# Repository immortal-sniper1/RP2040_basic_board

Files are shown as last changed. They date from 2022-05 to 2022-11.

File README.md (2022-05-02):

# RP2040_board1
 RP2040 test board, breadboard friedly.  
 Features:   
 -Li ion power optin (protection built in) auto switching power in case of usb unpluging   
 -RTC with separate 20mm cell  
 -microSD card slot  
 -all pins exposed (that are not used internaly for a dedicated task)  
 -both LDO and buck switching convertor for power, one of them may be used based on the SPDT switch   
 (later maybe just one of them may be populated and the switch replaced by a solder bridge)   
 -same pinout as rpi pico just wider form factor   
 -all pins labeled   
 -It requires a few extra wires to work since this is a 2 layer design and this was a scarifice 
made in order to keep a solid ground plane under the entire PCB   
 
 Images:  https://imgur.com/a/X6zGeTy

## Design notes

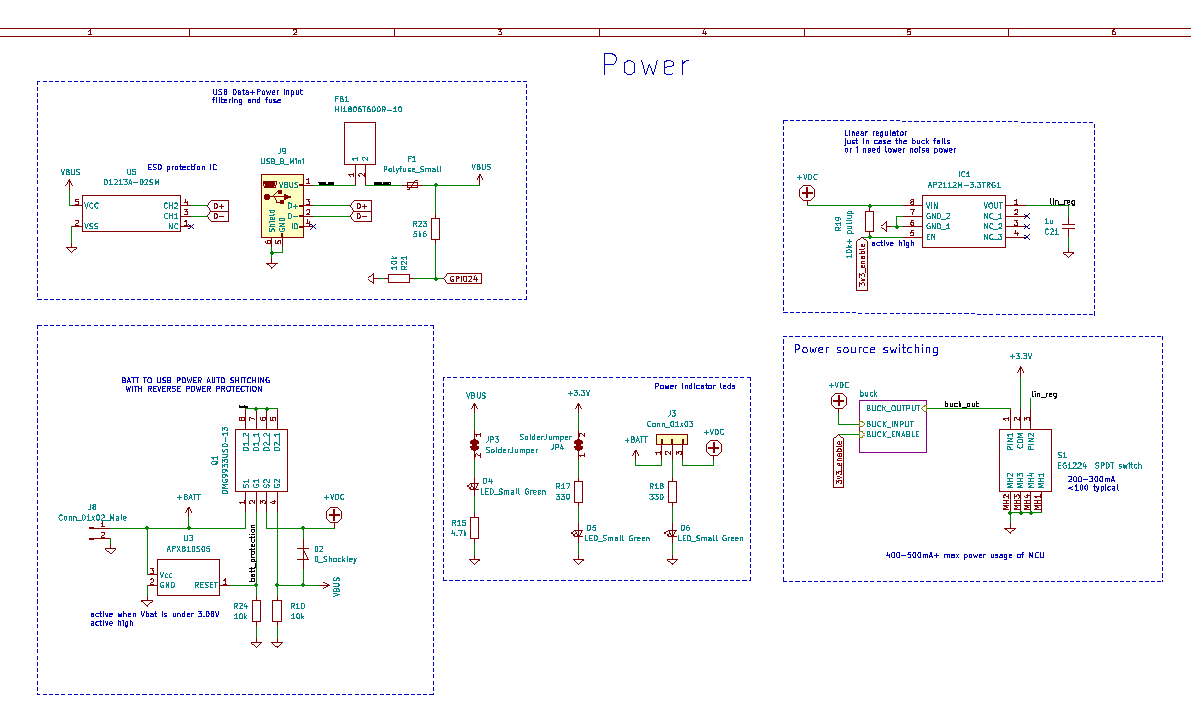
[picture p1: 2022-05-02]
HW_V2/pictures/Untitled3.png

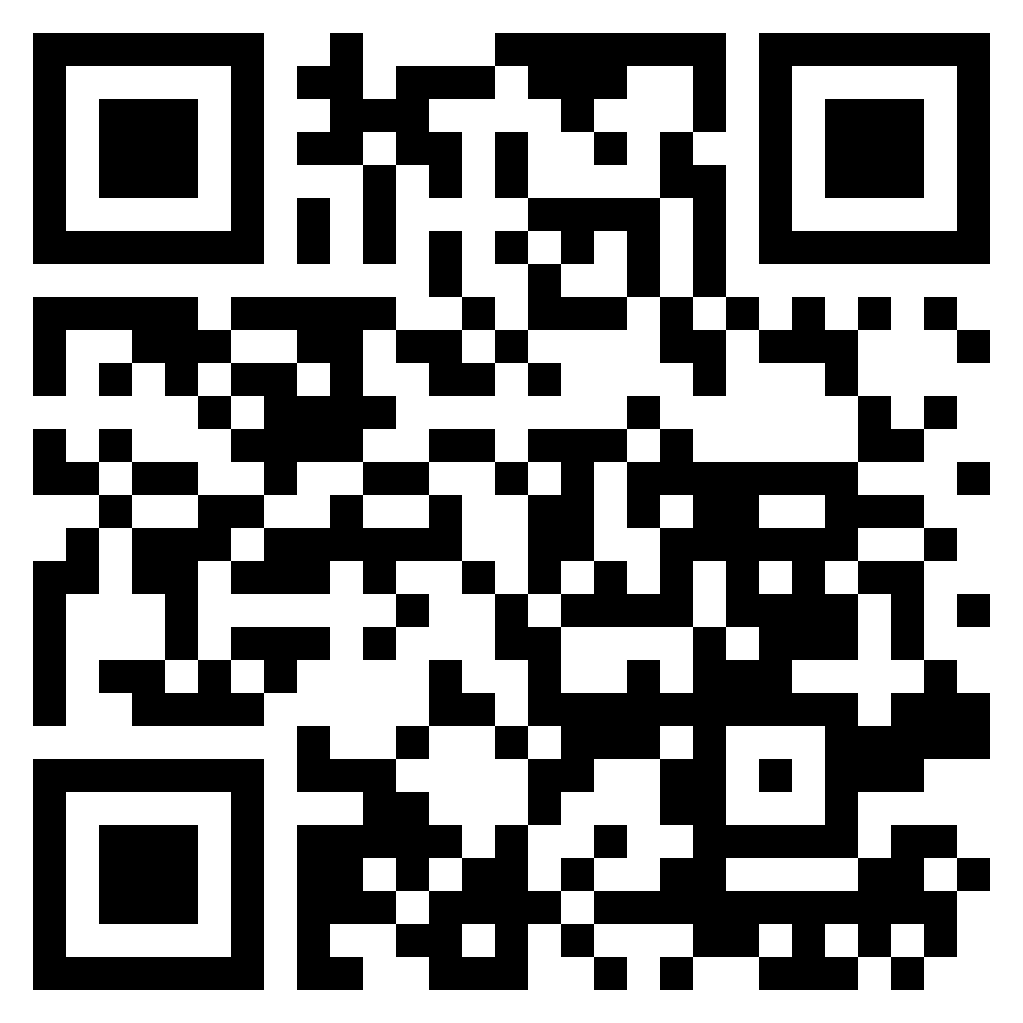
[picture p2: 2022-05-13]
HW_V2/pictures/QR.png

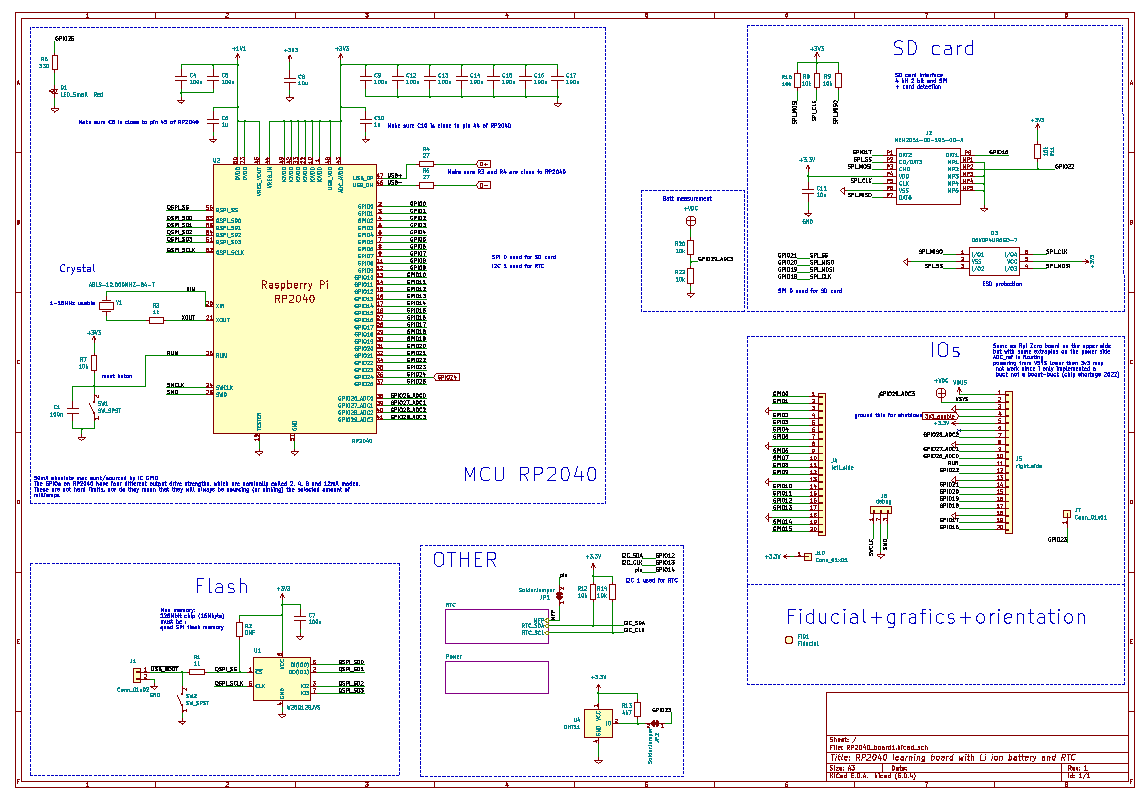
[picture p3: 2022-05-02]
HW_V2/pictures/Untitled1.png

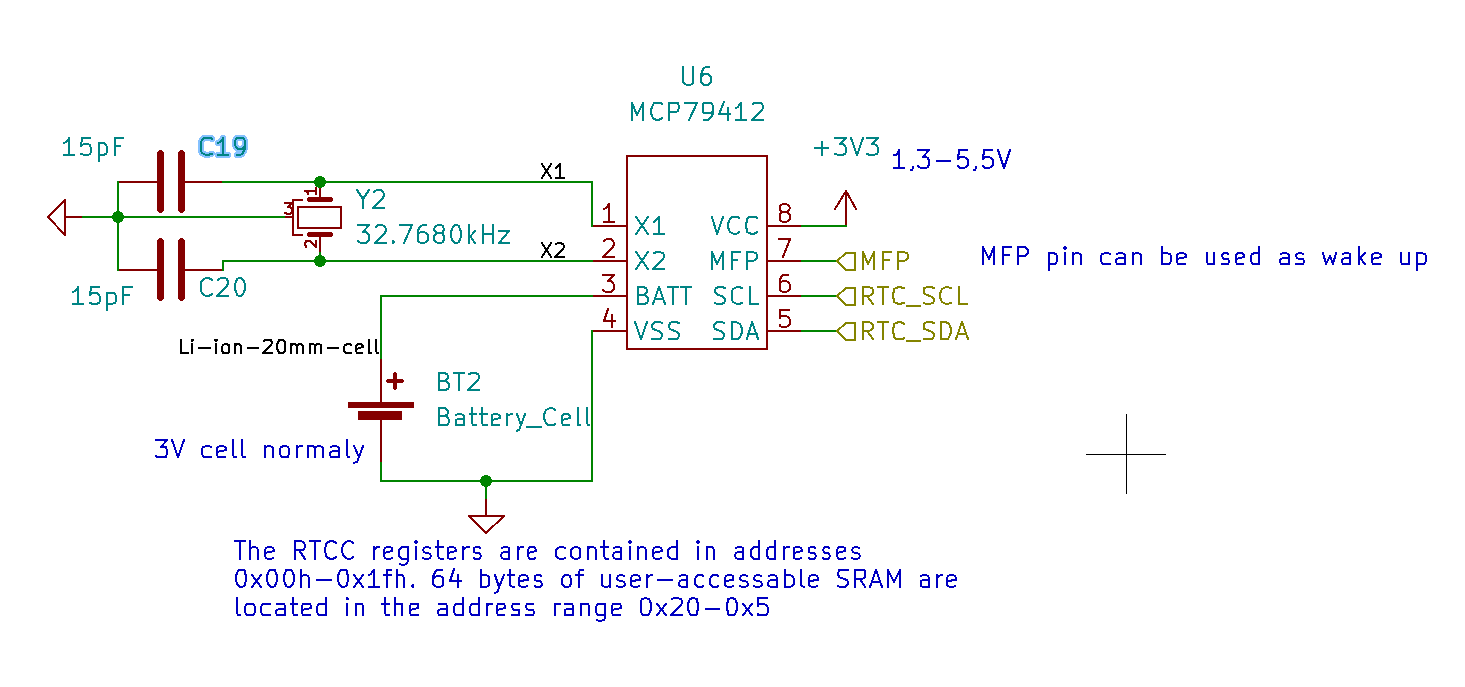
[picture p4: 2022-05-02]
HW_V2/pictures/Untitled2.png

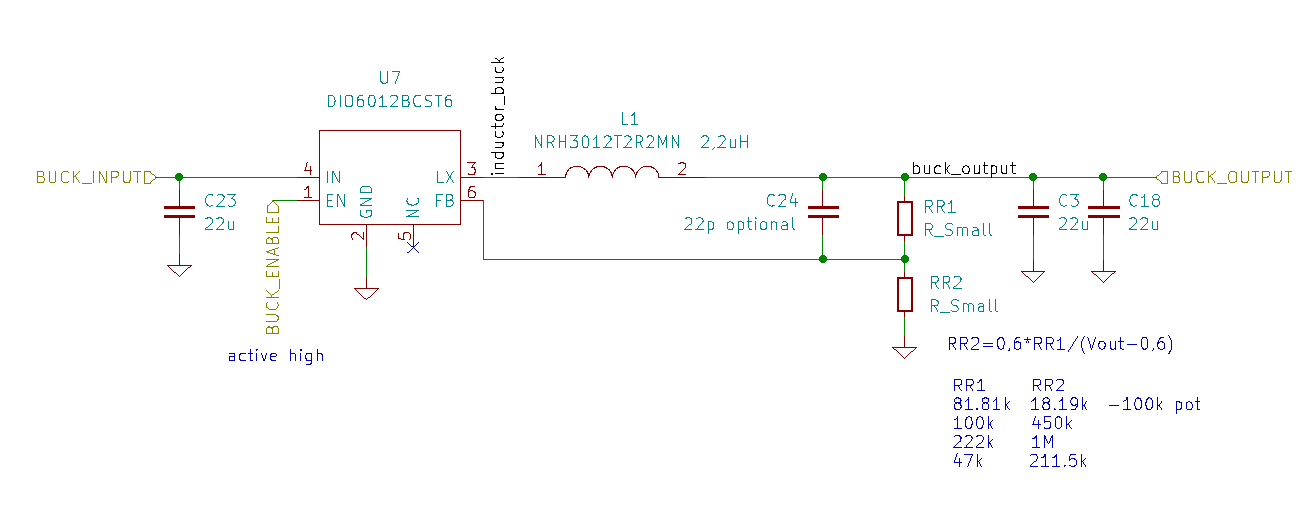
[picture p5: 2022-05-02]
HW_V2/pictures/Untitled4.png

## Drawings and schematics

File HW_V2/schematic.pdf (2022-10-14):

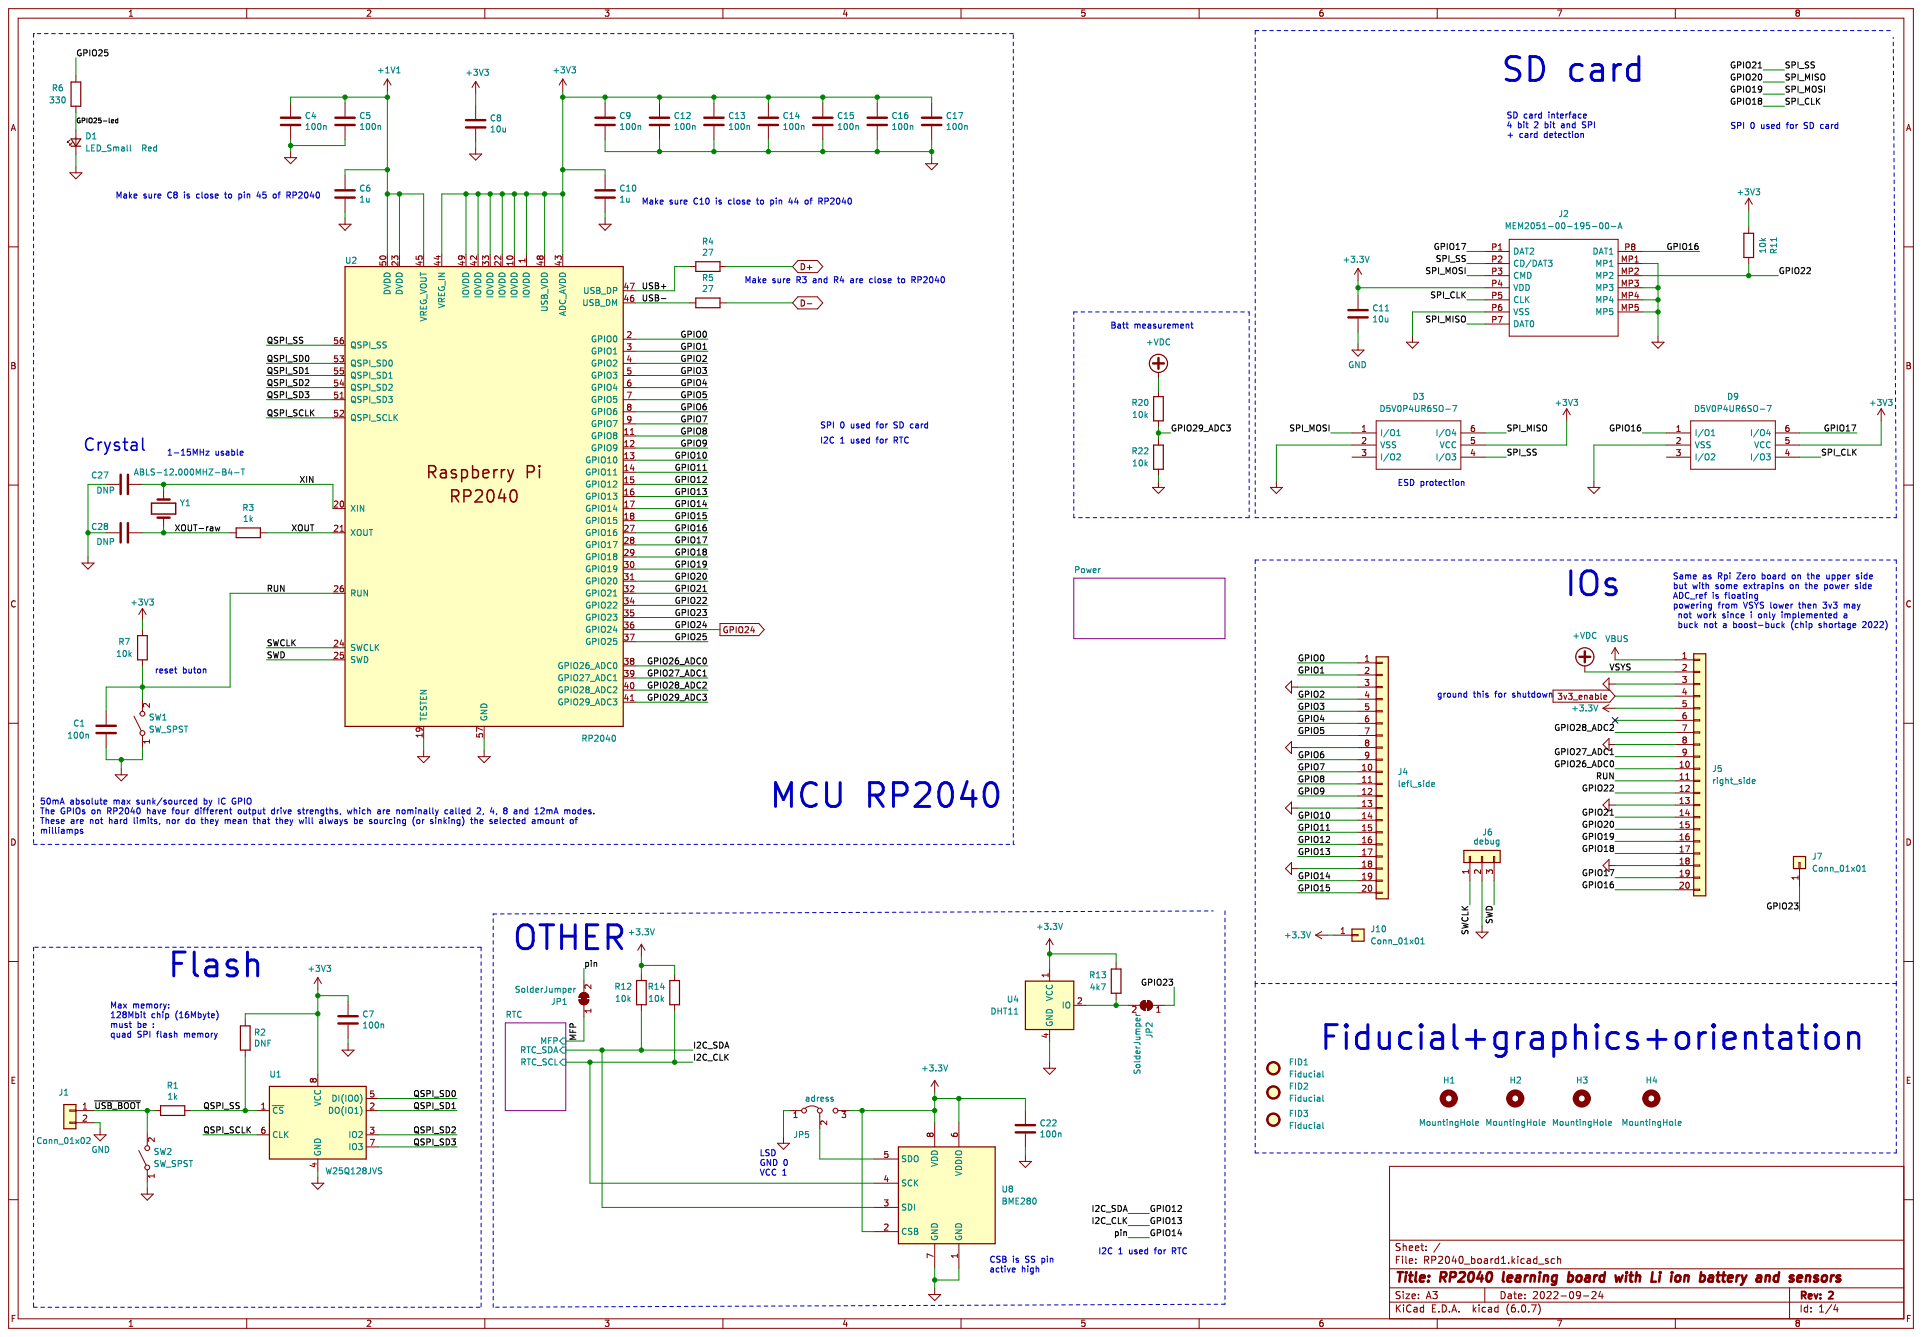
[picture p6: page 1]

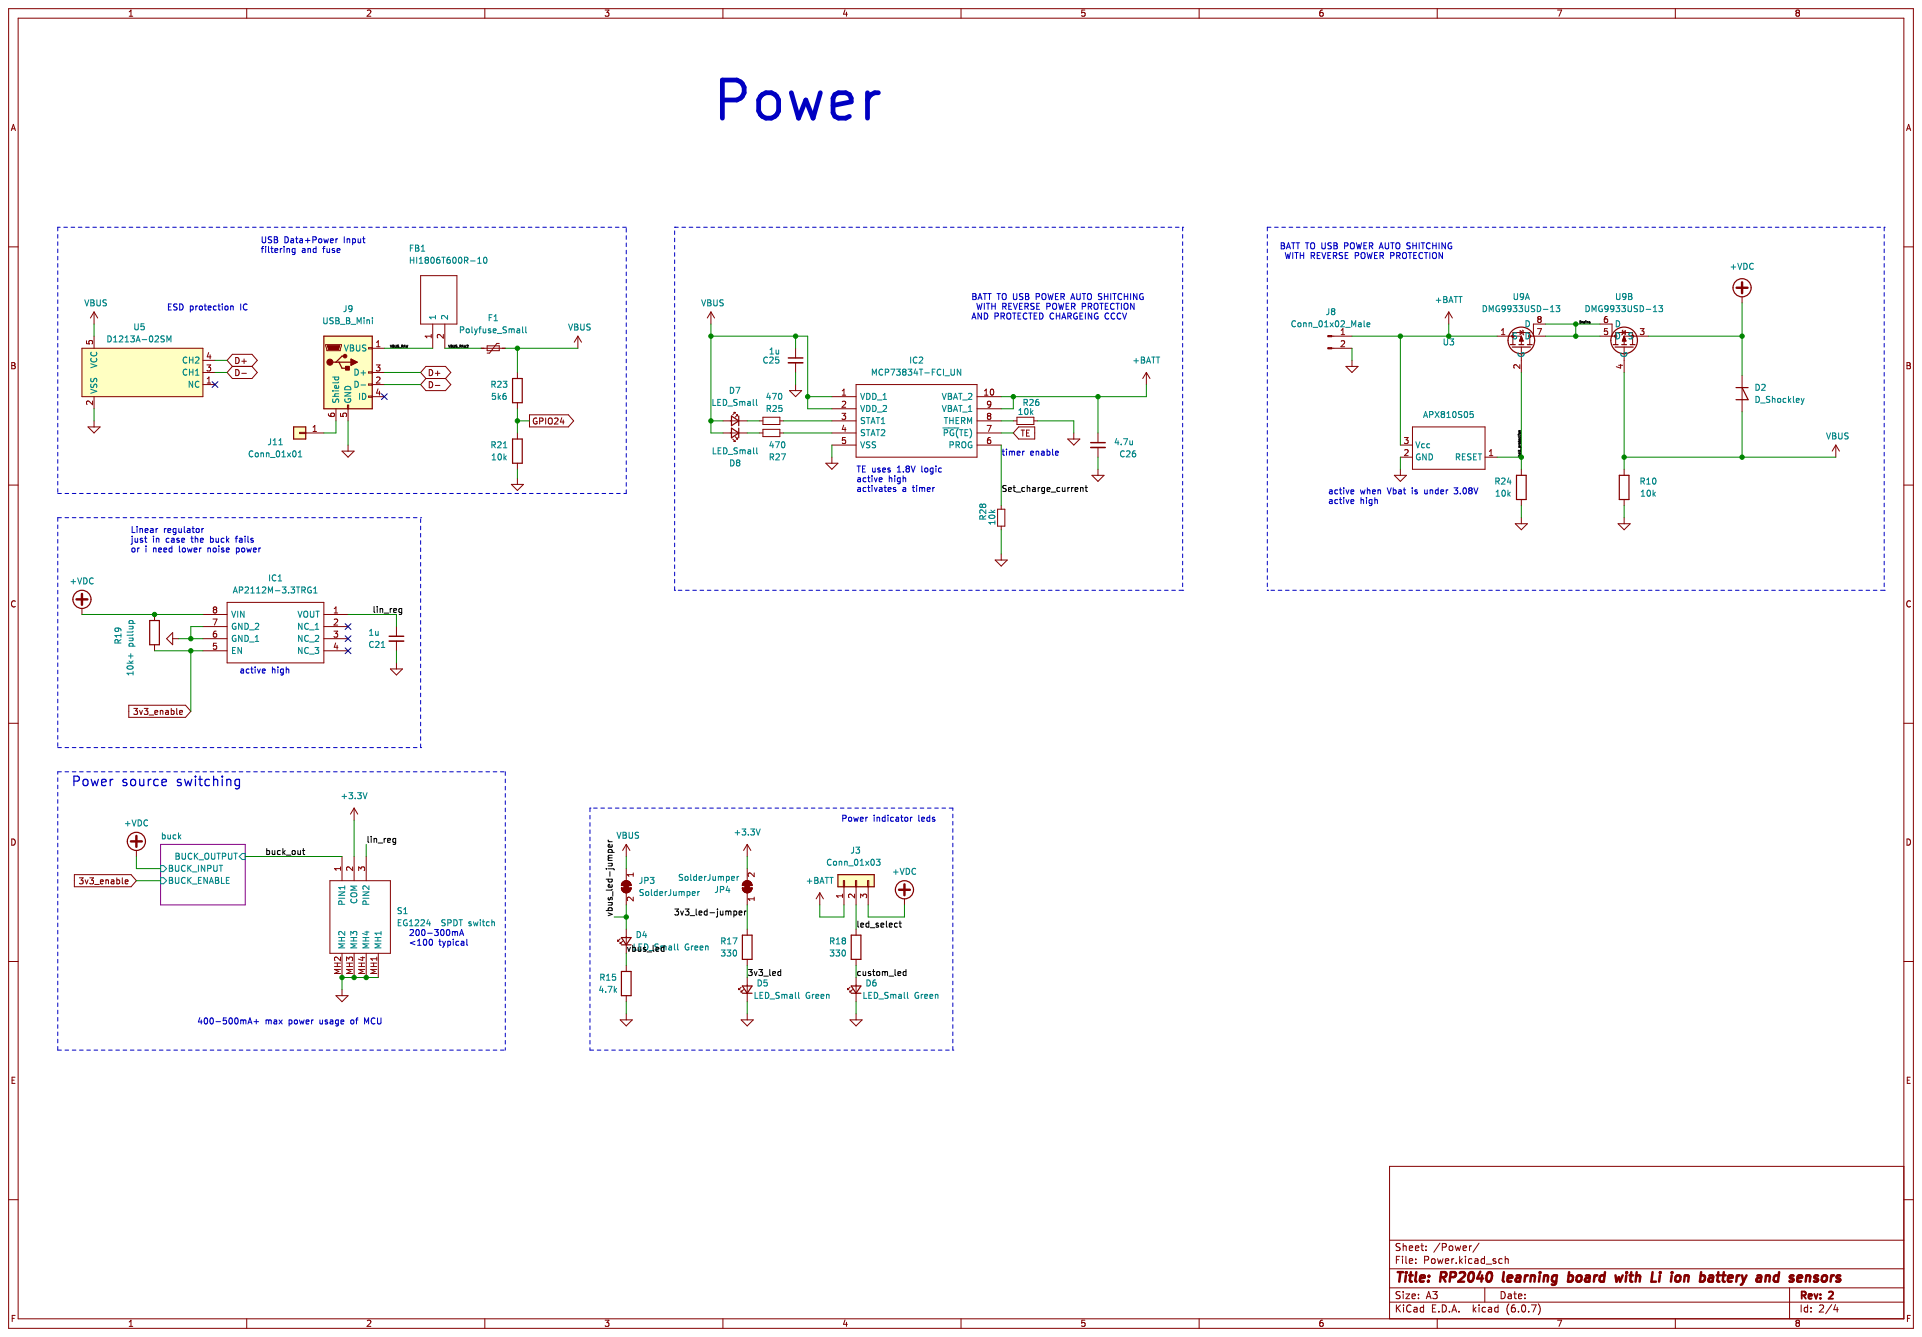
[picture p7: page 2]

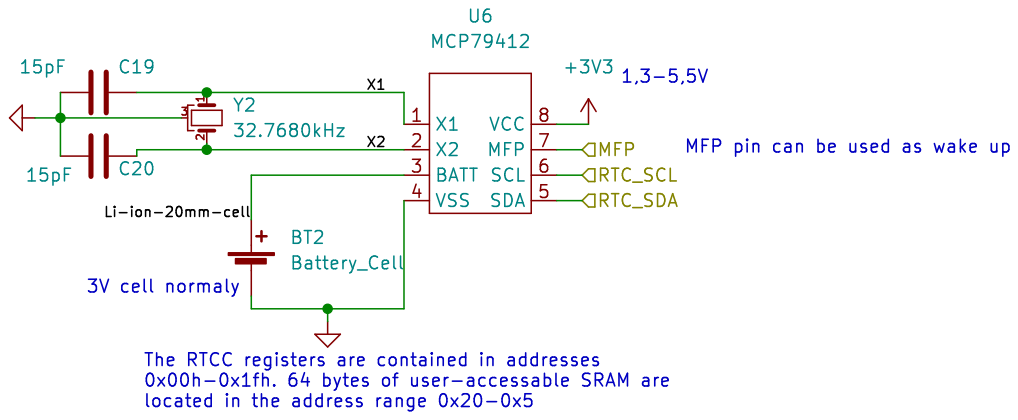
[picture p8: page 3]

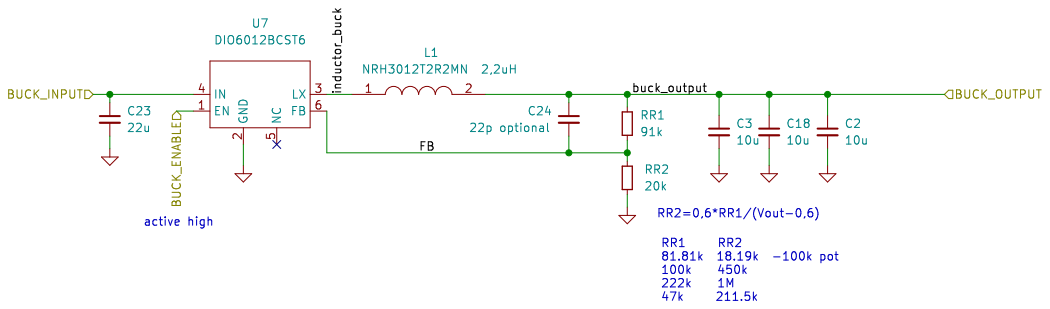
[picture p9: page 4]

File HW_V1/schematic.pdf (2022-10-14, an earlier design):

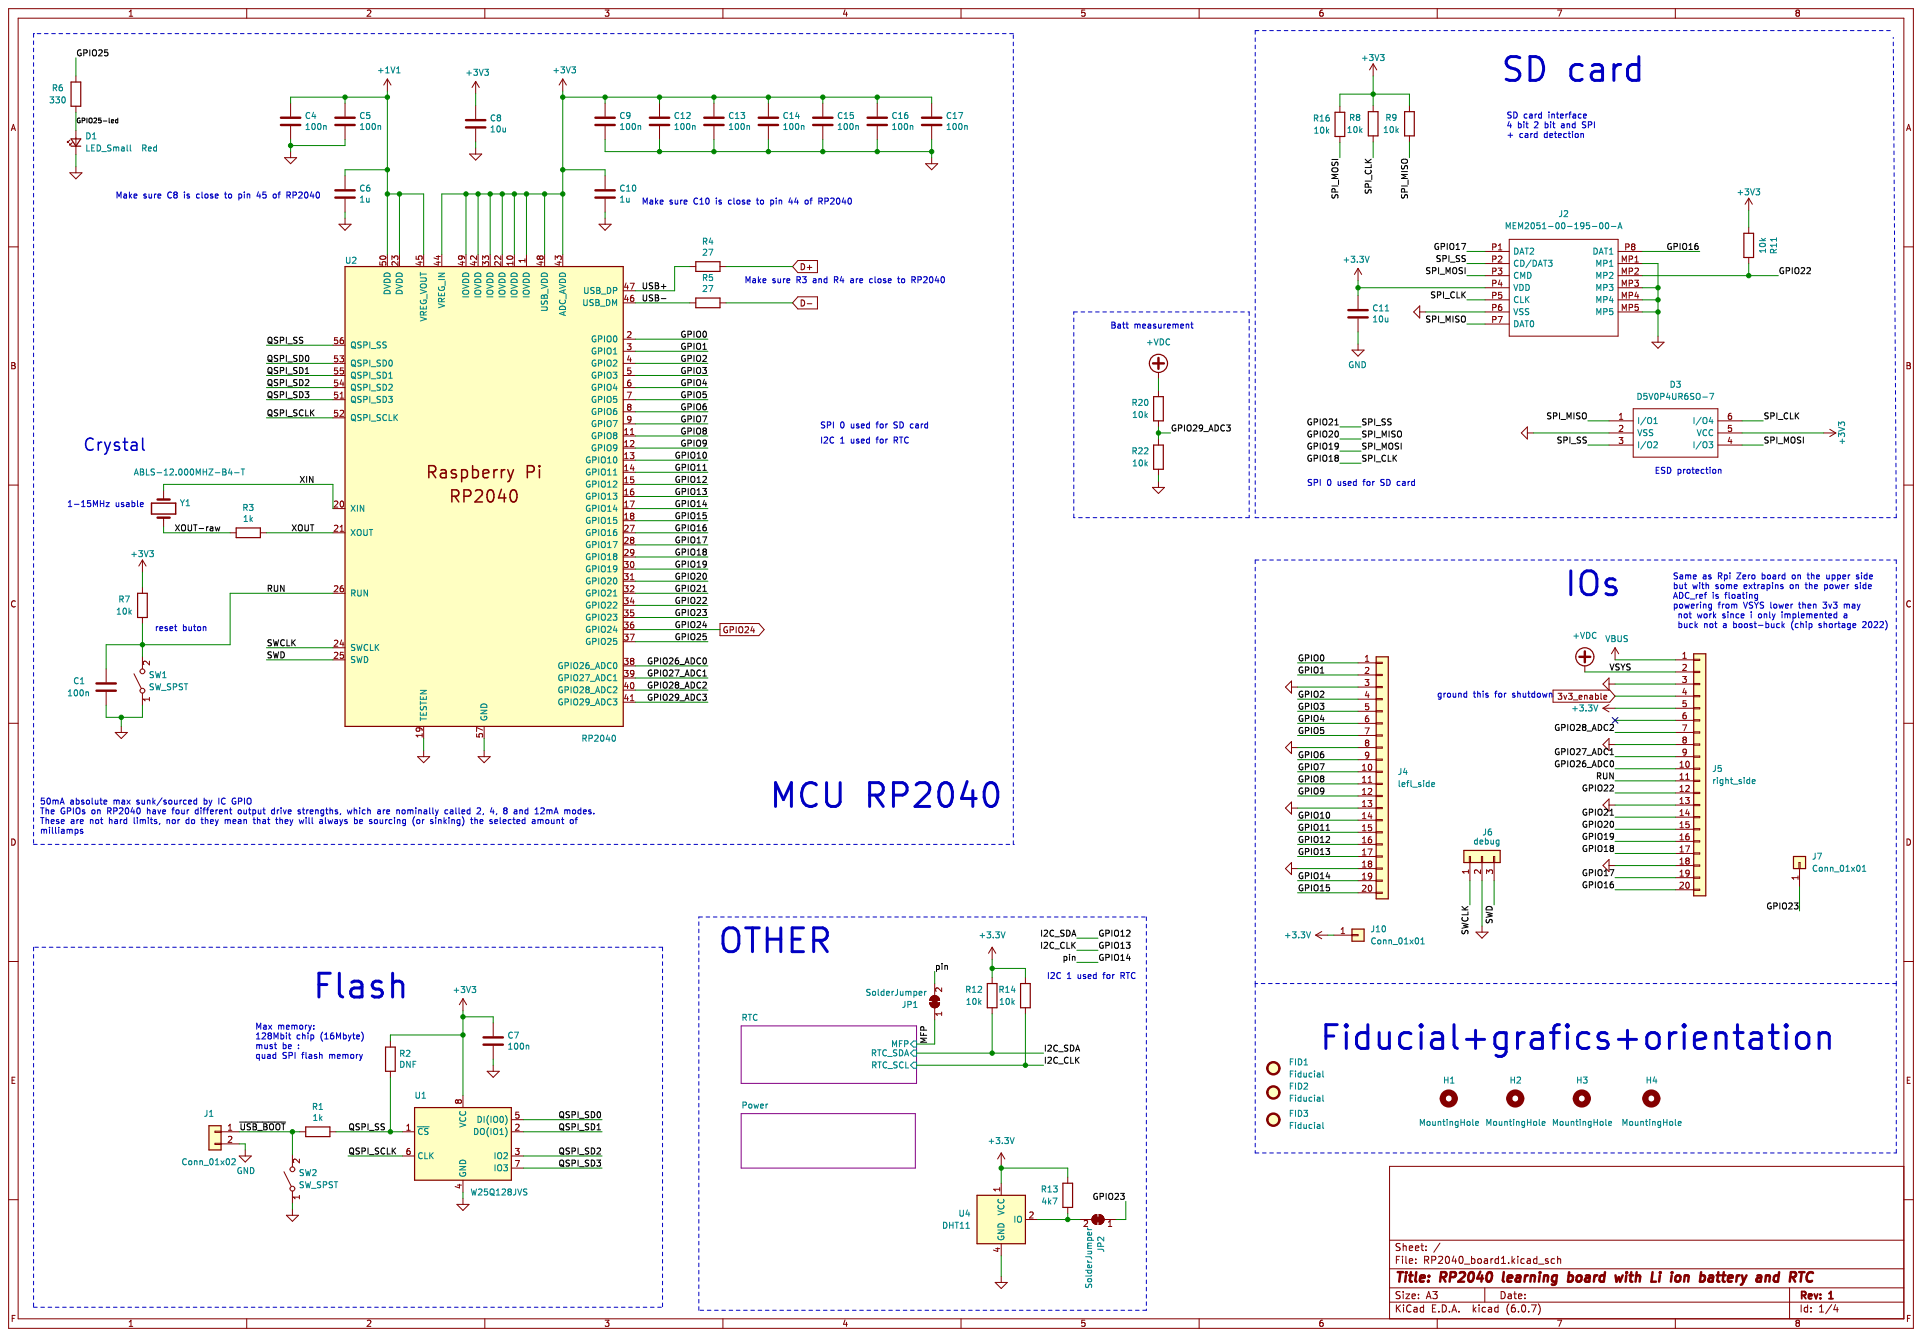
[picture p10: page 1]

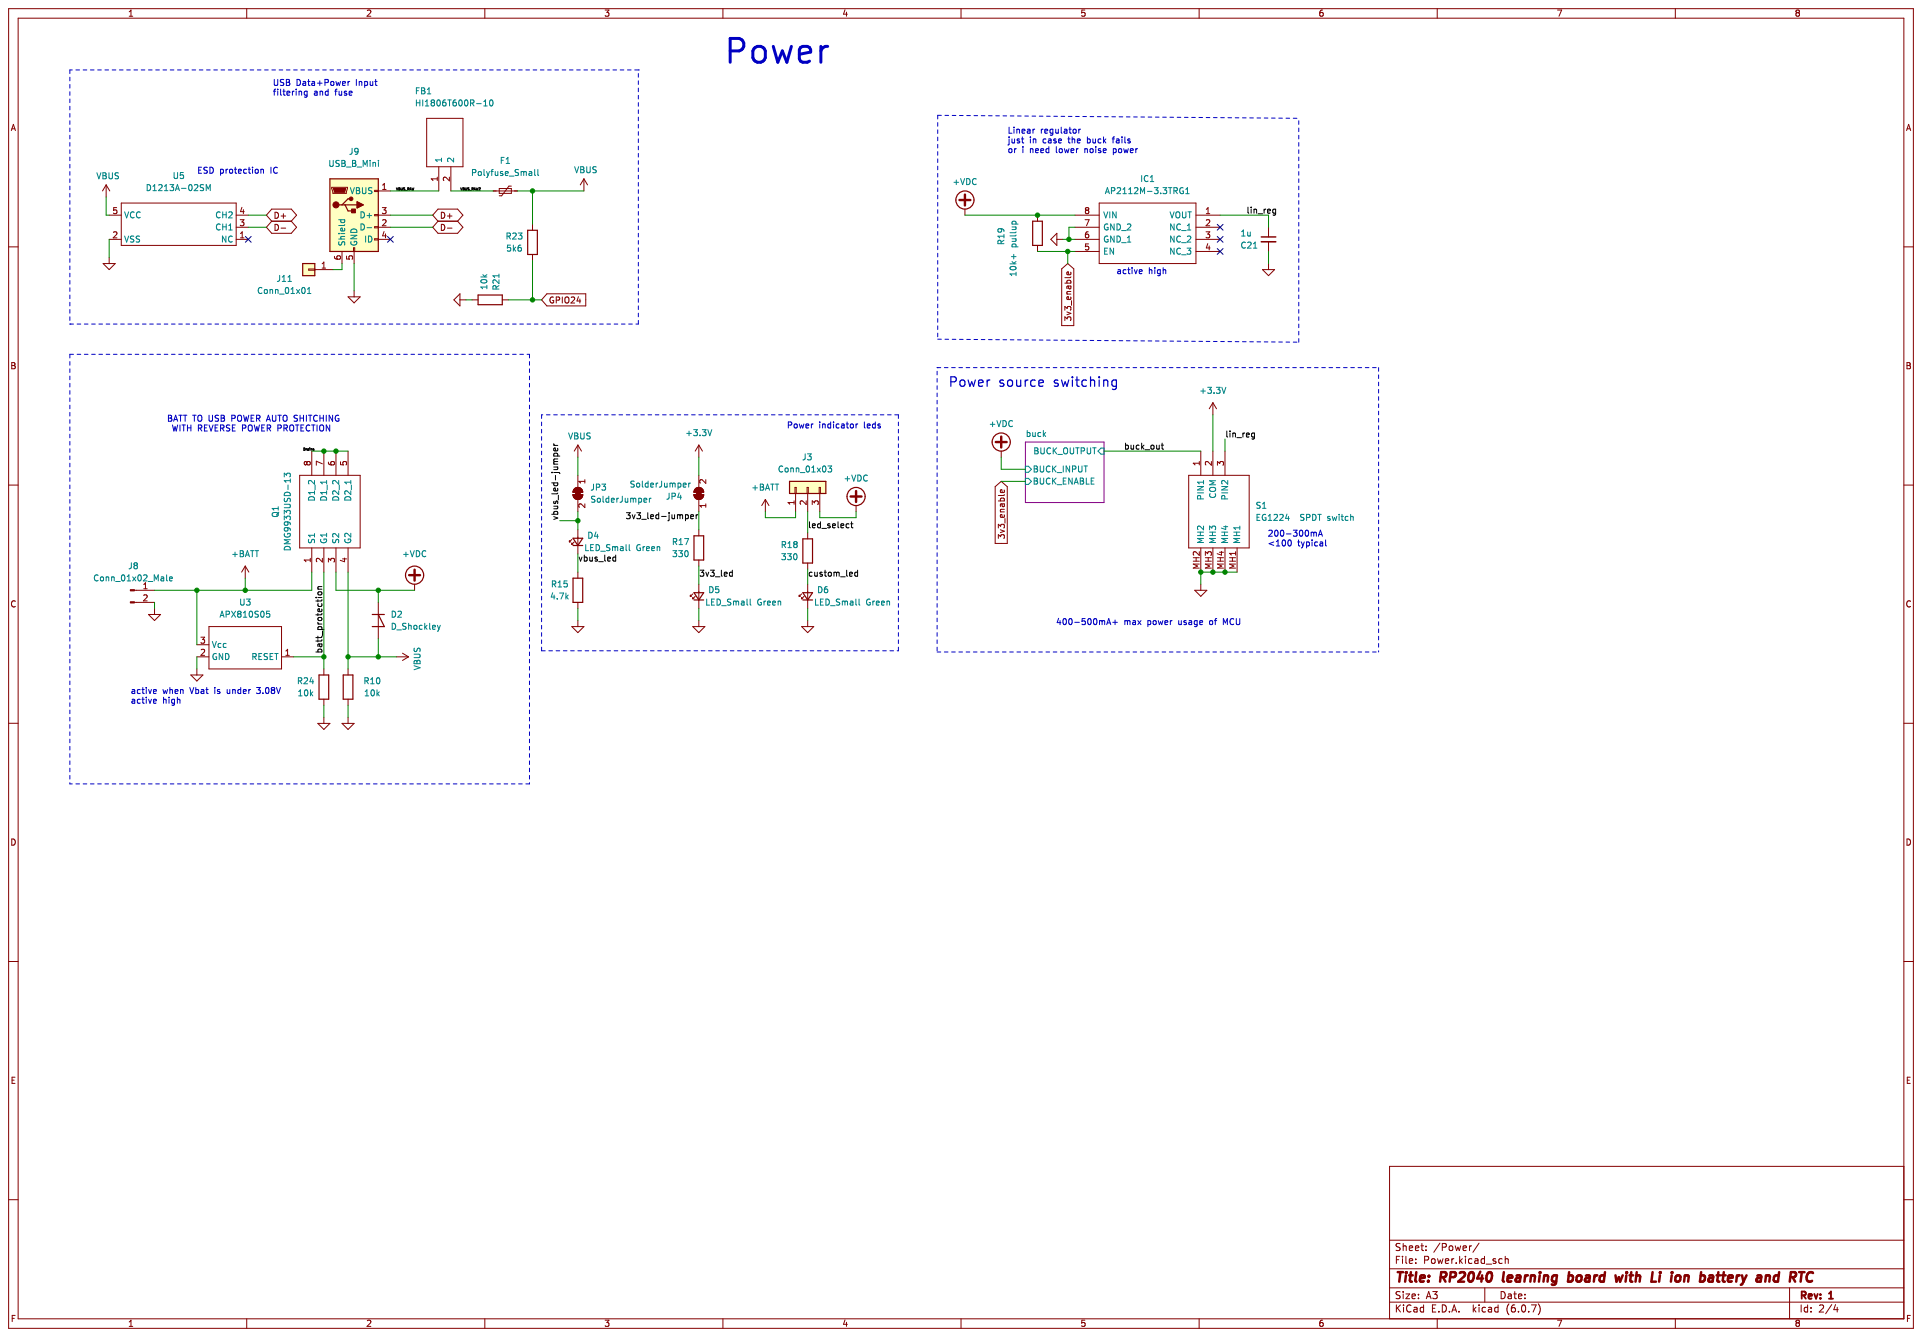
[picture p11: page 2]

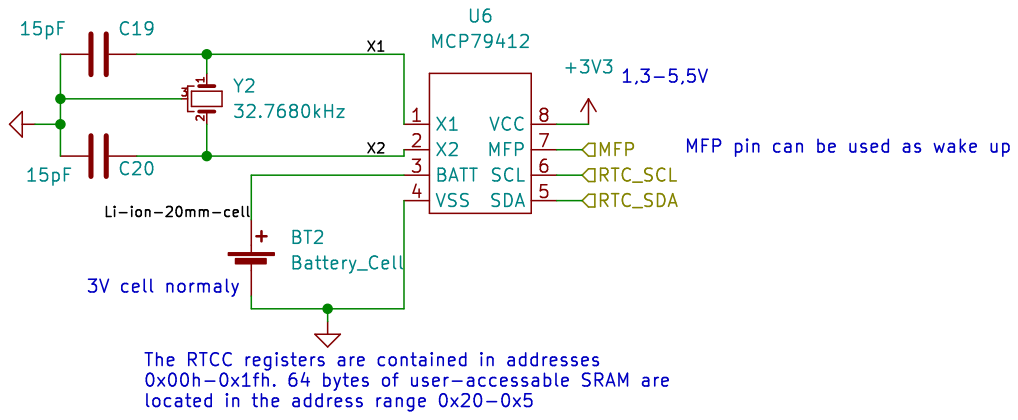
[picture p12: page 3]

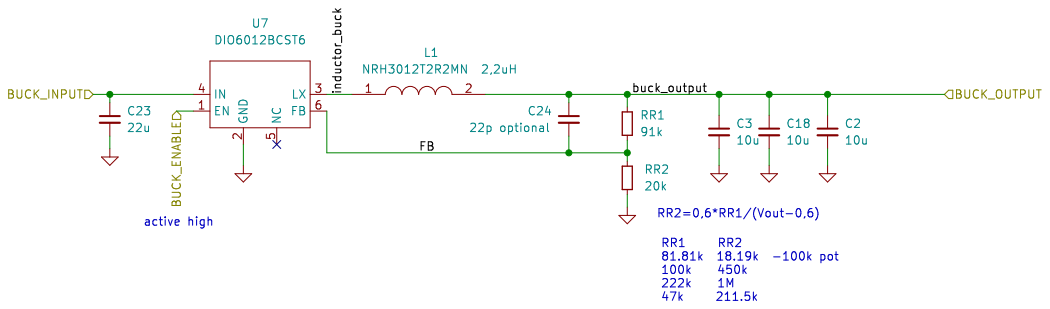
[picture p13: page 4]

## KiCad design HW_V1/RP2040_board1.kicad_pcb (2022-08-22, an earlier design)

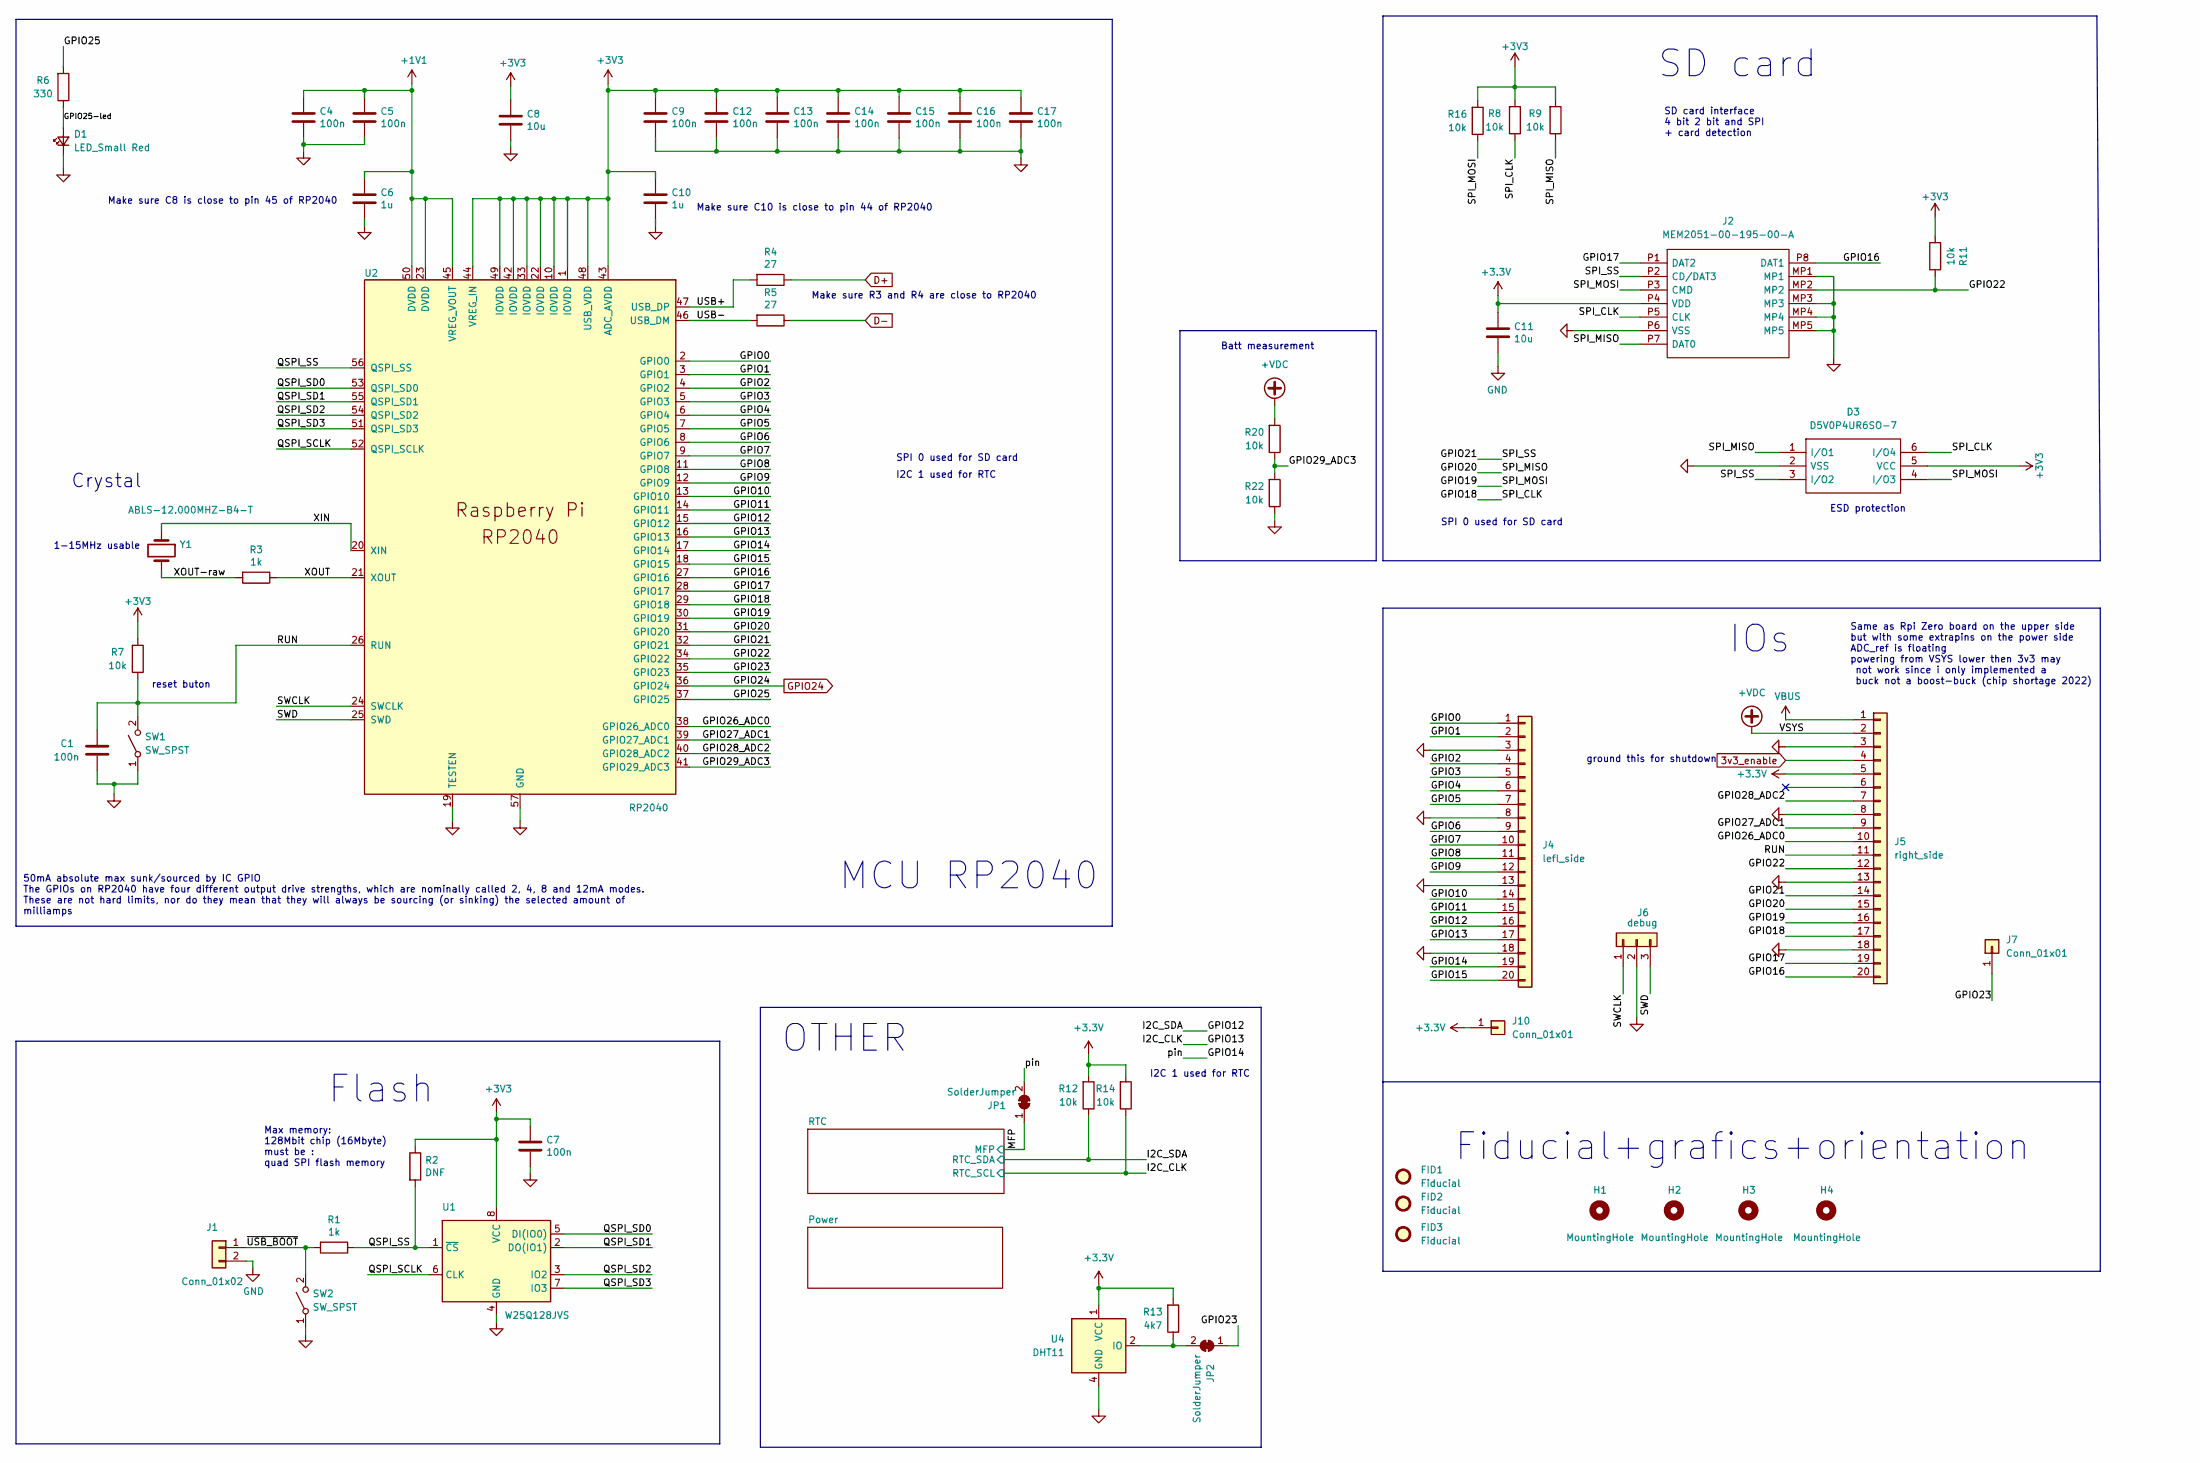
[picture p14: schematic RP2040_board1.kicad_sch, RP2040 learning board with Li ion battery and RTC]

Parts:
C1, C4, C5, C7, C9, C12, C13, C14, C15, C16, C17: 100n; C_0805_2012Metric_Pad1.18x1.45mm_HandSolder
C6, C10: 1u; C_0805_2012Metric_Pad1.18x1.45mm_HandSolder
C8: 10u; CP_Radial_D8.0mm_P3.50mm
C11: 10u; C_0603_1608Metric_Pad1.08x0.95mm_HandSolder
D1: LED_Small Red; LED_0603_1608Metric_Pad1.05x0.95mm_HandSolder
D3: D5V0P4UR6SO-7; SOT95P285X140-6N; Mouser Part Number 621-D5V0P4UR6SO-7
FID1: Fiducial; Fiducial_0.5mm_Mask1mm
FID2: Fiducial; KiCad-Logo2_8mm_SilkScreen
FID3: Fiducial; OSHW-Logo2_14.6x12mm_SilkScreen
H1, H2, H3, H4: MountingHole; MountingHole_3.2mm_M3
J1: Conn_01x02; PinHeader_1x02_P2.54mm_Vertical
J2: MEM2051-00-195-00-A; MEM20510019500A; Mouser Part Number 640-MEM20510019500A
J4: lefl_side; PinSocket_1x20_P2.54mm_Vertical
J5: right_side; PinSocket_1x20_P2.54mm_Vertical
J6: debug; PinSocket_1x03_P2.54mm_Vertical
J7, J10: Conn_01x01; PinSocket_1x01_P2.54mm_Vertical
JP1, JP2: SolderJumper; SolderJumper-2_P1.3mm_Bridged_RoundedPad1.0x1.5mm
R1, R3: 1k; R_0603_1608Metric_Pad0.98x0.95mm_HandSolder
R2: DNF; R_0603_1608Metric_Pad0.98x0.95mm_HandSolder
R4, R5: 27; R_0603_1608Metric_Pad0.98x0.95mm_HandSolder
R6: 330; R_0603_1608Metric_Pad0.98x0.95mm_HandSolder
R7, R8, R9, R11, R12, R14, R16, R20, R22: 10k; R_0603_1608Metric_Pad0.98x0.95mm_HandSolder
R13: 4k7; R_0603_1608Metric_Pad0.98x0.95mm_HandSolder
SW1, SW2: SW_SPST; PTS526SK15SMTR2LFS
U1: W25Q128JVS; SOIC-8_5.23x5.23mm_P1.27mm
U2: RP2040; RP2040-QFN-56
U4: DHT11; Aosong_DHT11_5.5x12.0_P2.54mm
Y1: ABLS-12.000MHZ-B4-T; ATS120SM

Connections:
3v3_enable: J5.4; also elsewhere on the board
+1V1: C4.1, C5.1, C6.1, U2.23 (DVDD), U2.45 (VREG_VOUT), U2.50 (DVDD)
+VDC: J5.2, R20.2; also elsewhere on the board
/GPIO0: J4.1, U2.2 (GPIO0)
/GPIO1: J4.2, U2.3 (GPIO1)
/GPIO2: J4.4, U2.4 (GPIO2)
/GPIO3: J4.5, U2.5 (GPIO3)
/GPIO4: J4.6, U2.6 (GPIO4)
/GPIO5: J4.7, U2.7 (GPIO5)
/GPIO6: J4.9, U2.8 (GPIO6)
/GPIO7: J4.10, U2.9 (GPIO7)
/GPIO8: J4.11, U2.11 (GPIO8)
/GPIO9: J4.12, U2.12 (GPIO9)
/GPIO10: J4.14, U2.13 (GPIO10)
/GPIO11: J4.15, U2.14 (GPIO11)
/GPIO12: J4.16, R12.1, U2.15 (GPIO12); also elsewhere on the board
/GPIO13: J4.17, R14.1, U2.16 (GPIO13); also elsewhere on the board
/GPIO14: J4.19, JP1.2 (B), U2.17 (GPIO14)
/GPIO15: J4.20, U2.18 (GPIO15)
/GPIO16: J2.P8 (DAT1), J5.20, U2.27 (GPIO16)
/GPIO17: J2.P1 (DAT2), J5.19, U2.28 (GPIO17)
/GPIO18: D3.6 (I/O4), J2.P5 (CLK), J5.17, R8.1, U2.29 (GPIO18)
/GPIO19: D3.4 (I/O3), J2.P3 (CMD), J5.16, R16.1, U2.30 (GPIO19)
/GPIO20: D3.1 (I/O1), J2.P7 (DAT0), J5.15, R9.1, U2.31 (GPIO20)
/GPIO21: D3.3 (I/O2), J2.P2 (CD/DAT3), J5.14, U2.32 (GPIO21)
/GPIO22: J2.MP2, J5.12, R11.1, U2.34 (GPIO22)
/GPIO23: J7.1, JP2.1 (A), U2.35 (GPIO23)
/GPIO25: R6.2, U2.37 (GPIO25)
/GPIO25-led: D1.2 (A), R6.1
/GPIO26_ADC0: J5.10, U2.38 (GPIO26_ADC0)
/GPIO27_ADC1: J5.9, U2.39 (GPIO27_ADC1)
/GPIO28_ADC2: J5.7, U2.40 (GPIO28_ADC2)
/GPIO29_ADC3: R20.1, R22.2, U2.41 (GPIO29_ADC3)
/MFP: JP1.1 (A); also elsewhere on the board
/QSPI_SCLK: U1.6 (CLK), U2.52 (QSPI_SCLK)
/QSPI_SD0: U1.5 (DI(IO0)), U2.53 (QSPI_SD0)
/QSPI_SD1: U1.2 (DO(IO1)), U2.55 (QSPI_SD1)
/QSPI_SD2: U1.3 (IO2), U2.54 (QSPI_SD2)
/QSPI_SD3: U1.7 (IO3), U2.51 (QSPI_SD3)
/QSPI_SS: R1.1, R2.2, U1.1 (~CS), U2.56 (QSPI_SS)
/RUN: C1.1, J5.11, R7.1, SW1.2 (B), U2.26 (RUN)
/SWCLK: J6.1, U2.24 (SWCLK)
/SWD: J6.3, U2.25 (SWD)
/USB+: R4.2, U2.47 (USB_DP)
/USB-: R5.2, U2.46 (USB_DM)
/XIN: U2.20 (XIN), Y1.1
/XOUT: R3.1, U2.21 (XOUT)
/XOUT-raw: R3.2, Y1.2
/~USB_BOOT: J1.1, R1.2, SW2.2 (B)
D+: R4.1; also elsewhere on the board
D-: R5.1; also elsewhere on the board
GND: C1.2, C4.2, C5.2, C6.2, C7.2, C8.2, C9.2, C10.2, C11.2, C12.2, C13.2, C14.2, C15.2, C16.2, C17.2, D1.1 (K), D3.2 (VSS), J1.2, J2.MP1, J2.MP3, J2.MP4, J2.MP5, J2.P6 (VSS), J4.3, J4.8, J4.13, J4.18, J5.3, J5.8, J5.13, J5.18, J6.2, R22.1, SW1.1 (A), SW2.1 (A), U1.4 (GND), U2.19 (TESTEN), U2.57 (GND), U4.4 (GND); also elsewhere on the board
GPIO24: U2.36 (GPIO24); also elsewhere on the board
unnamed: JP2.2 (B), R13.1, U4.2 (IO)
VBUS: J5.1; also elsewhere on the board

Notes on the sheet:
I2C 1 used for RTC
Fiducial+grafics+orientation
SD card interface 4 bit 2 bit and SPI + card detection
OTHER
50mA absolute max sunk/sourced by IC GPIO The GPIOs on RP2040 have four different output drive strengths, which are nominally called 2, 4, 8 and 12mA modes. These are not hard limits, nor do they mean that they will always be sourcing (or sinking) the selected amount of milliamps
IOs
Same as Rpi Zero board on the upper side but with some extrapins on the power side ADC_ref is floating powering from VSYS lower then 3v3 may not work since i only implemented a buck not a boost-buck (chip shortage 2022)
Flash
ground this for shutdown
Crystal
SD card
MCU RP2040
Make sure C8 is close to pin 45 of RP2040
SPI 0 used for SD card
Make sure R3 and R4 are close to RP2040
Max memory: 128Mbit chip (16Mbyte) must be : quad SPI flash memory
1-15MHz usable
Make sure C10 is close to pin 44 of RP2040
reset buton
ESD protection
Batt measurement

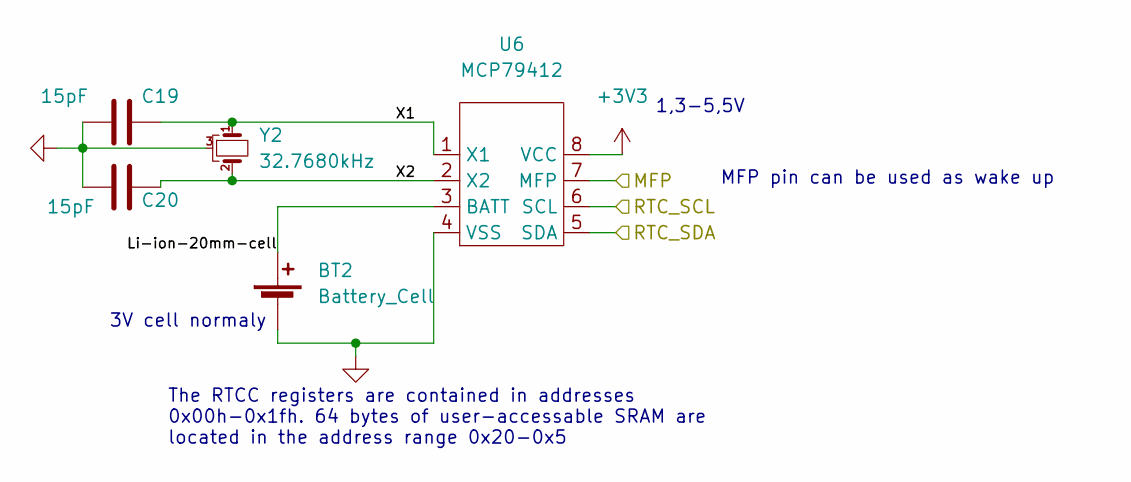
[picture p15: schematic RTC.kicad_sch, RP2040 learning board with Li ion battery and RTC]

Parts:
BT2: Battery_Cell; BATHLD001THM
C19, C20: 15pF; C_0603_1608Metric_Pad1.08x0.95mm_HandSolder
U6: MCP79412; TSSOP-8_4.4x3mm_P0.65mm
Y2: 32.7680kHz; Crystal_C38-LF_D3.0mm_L8.0mm_Vertical

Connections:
/GPIO12: U6.5 (SDA); also elsewhere on the board
/GPIO13: U6.6 (SCL); also elsewhere on the board
/MFP: U6.7 (MFP); also elsewhere on the board
/RTC/Li-ion-20mm-cell: BT2.1 (+), U6.3 (BATT)
/RTC/X1: C19.2, U6.1 (X1), Y2.1
/RTC/X2: C20.2, U6.2 (X2), Y2.2
GND: BT2.2 (-), C19.1, C20.1, U6.4 (VSS), Y2.3; also elsewhere on the board

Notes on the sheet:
1,3-5,5V
3V cell normaly
MFP pin can be used as wake up
The RTCC registers are contained in addresses 0x00h-0x1fh. 64 bytes of user-accessable SRAM are located in the address range 0x20-0x5

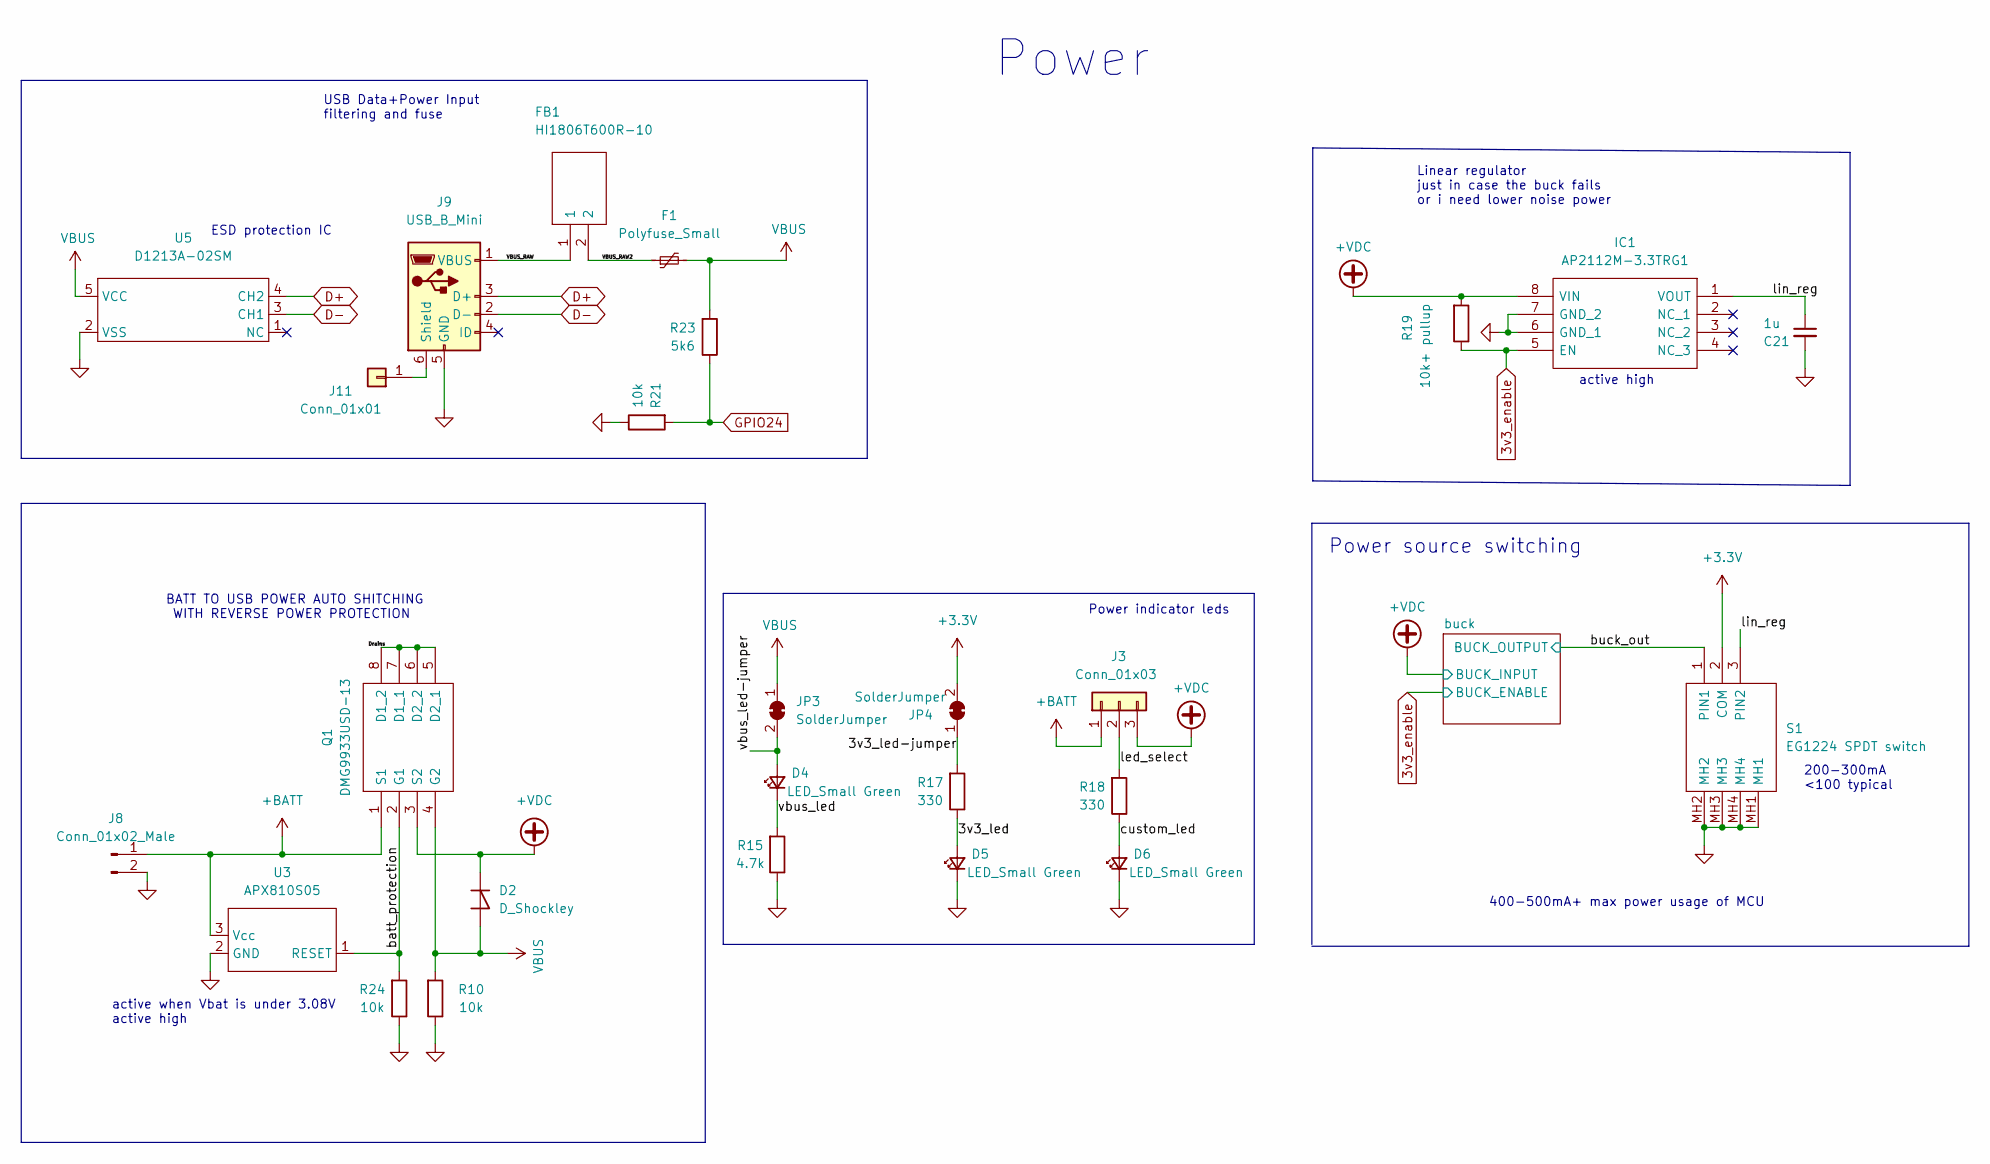
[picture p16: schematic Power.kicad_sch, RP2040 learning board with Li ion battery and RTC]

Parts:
C21: 1u; C_0805_2012Metric_Pad1.18x1.45mm_HandSolder
D2: D_Shockley; D_DO-15_P5.08mm_Vertical_KathodeUp
D4, D5, D6: LED_Small Green; LED_0603_1608Metric_Pad1.05x0.95mm_HandSolder
F1: Polyfuse_Small; Fuse_1812_4532Metric_Pad1.30x3.40mm_HandSolder
FB1: HI1806T600R-10; BEADC4516X185N; Mouser Part Number 875-HI1806T600R-10
IC1: AP2112M-3.3TRG1; SOIC127P600X170-8N; Mouser Part Number 621-AP2112M-3.3TRG1
J3: Conn_01x03; PinHeader_1x03_P2.54mm_Vertical
J8: Conn_01x02_Male; PinHeader_1x02_P2.54mm_Vertical
J9: USB_B_Mini; USB_Mini-B_Lumberg_2486_01_Horizontal
J11: Conn_01x01; PinSocket_1x01_P2.54mm_Vertical
JP3, JP4: SolderJumper; SolderJumper-2_P1.3mm_Bridged_RoundedPad1.0x1.5mm
Q1: DMG9933USD-13; SOIC127P600X175-8N; Mouser Part Number 621-DMG9933USD-13
R10, R21, R24: 10k; R_0603_1608Metric_Pad0.98x0.95mm_HandSolder
R15: 4.7k; R_Axial_DIN0204_L3.6mm_D1.6mm_P5.08mm_Vertical
R17, R18: 330; R_0603_1608Metric_Pad0.98x0.95mm_HandSolder
R19: 10k+ pullup; R_0603_1608Metric_Pad0.98x0.95mm_HandSolder
R23: 5k6; R_0603_1608Metric_Pad0.98x0.95mm_HandSolder
S1: EG1224 SPDT switch; EG1224; Mouser Part Number 612-EG1224
U3: APX810S05; SOT-23
U5: D1213A-02SM; SOT-23-5_HandSoldering

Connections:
3v3_enable: IC1.5 (EN), R19.1; also elsewhere on the board
+BATT: J3.1, J8.1, Q1.1 (S1), U3.3 (Vcc)
+VDC: D2.1 (K), IC1.8 (VIN), J3.3, Q1.3 (S2), R19.2; also elsewhere on the board
/Power/3v3_led: D5.2 (A), R17.1
/Power/3v3_led-jumper: JP4.1 (A), R17.2
/Power/Drains: Q1.5 (D2_1), Q1.6 (D2_2), Q1.7 (D1_1), Q1.8 (D1_2)
/Power/VBUS_RAW: FB1.1, J9.1 (VBUS)
/Power/VBUS_RAW2: F1.1, FB1.2
/Power/batt_protection: Q1.2 (G1), R24.2, U3.1 (RESET)
/Power/buck_out: S1.1 (PIN1); also elsewhere on the board
/Power/custom_led: D6.2 (A), R18.1
/Power/led_select: J3.2, R18.2
/Power/lin_reg: C21.1, IC1.1 (VOUT), S1.3 (PIN2)
/Power/vbus_led: D4.1 (K), R15.2
/Power/vbus_led-jumper: D4.2 (A), JP3.2 (B)
D+: J9.3 (D+), U5.4 (CH2); also elsewhere on the board
D-: J9.2 (D-), U5.3 (CH1); also elsewhere on the board
GND: C21.2, D5.1 (K), D6.1 (K), IC1.6 (GND_1), IC1.7 (GND_2), J8.2, J9.5 (GND), R10.1, R15.1, R21.1, R24.1, S1.MH1, S1.MH2, S1.MH3, S1.MH4, U3.2 (GND), U5.2 (VSS); also elsewhere on the board
GPIO24: R21.2, R23.1; also elsewhere on the board
unnamed: J9.6 (Shield), J11.1
VBUS: D2.2 (A), F1.2, JP3.1 (A), Q1.4 (G2), R10.2, R23.2, U5.5 (VCC); also elsewhere on the board

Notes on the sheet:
400-500mA+ max power usage of MCU
ESD protection IC
active when Vbat is under 3.08V active high
Power indicator leds
Linear regulator just in case the buck fails or i need lower noise power
200-300mA <100 typical
USB Data+Power Input filtering and fuse
Power source switching
Power
active high
BATT TO USB POWER AUTO SHITCHING WITH REVERSE POWER PROTECTION

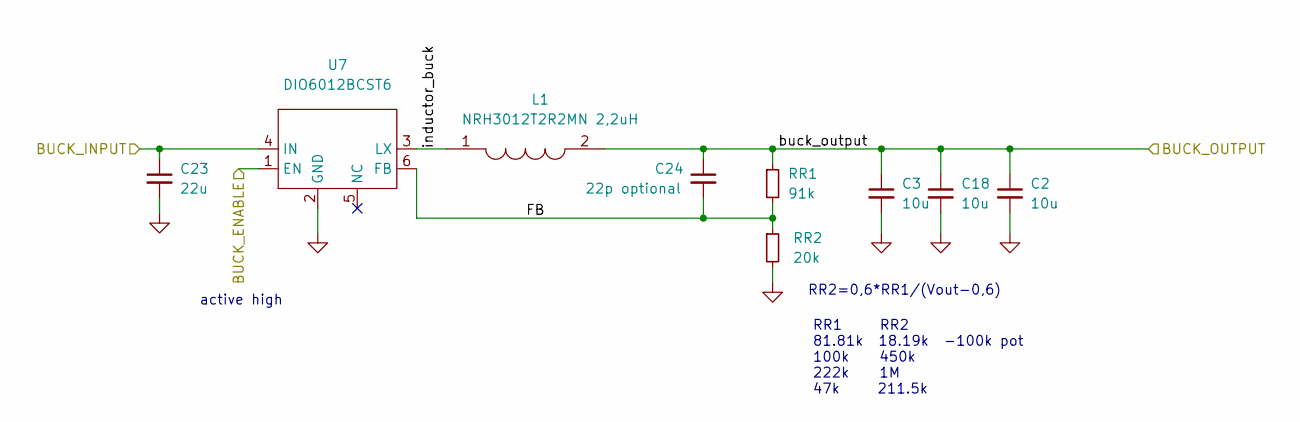
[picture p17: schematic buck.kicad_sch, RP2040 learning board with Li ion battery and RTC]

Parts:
C2, C3, C18: 10u; C_0805_2012Metric
C23: 22u; CP_Radial_D5.0mm_P2.00mm
C24: 22p optional; C_0603_1608Metric_Pad1.08x0.95mm_HandSolder
L1: NRH3012T2R2MN 2,2uH; NRH3012T220MNV; Mouser Part Number 963-NRH3012T2R2MN
RR1: 91k; R_0805_2012Metric
RR2: 20k; R_0805_2012Metric
U7: DIO6012BCST6; SOT-23-6_Handsoldering

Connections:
3v3_enable: U7.1 (EN); also elsewhere on the board
+VDC: C23.1, U7.4 (IN); also elsewhere on the board
/Power/buck/FB: C24.2, RR1.2, RR2.1, U7.6 (FB)
/Power/buck/inductor_buck: L1.1, U7.3 (LX)
/Power/buck_out: C2.1, C3.1, C18.1, C24.1, L1.2, RR1.1; also elsewhere on the board
GND: C2.2, C3.2, C18.2, C23.2, RR2.2, U7.2 (GND); also elsewhere on the board

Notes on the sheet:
RR2=0,6*RR1/(Vout-0,6)
active high
RR1 RR2 81.81k 18.19k -100k pot 100k 450k 222k 1M 47k 211.5k

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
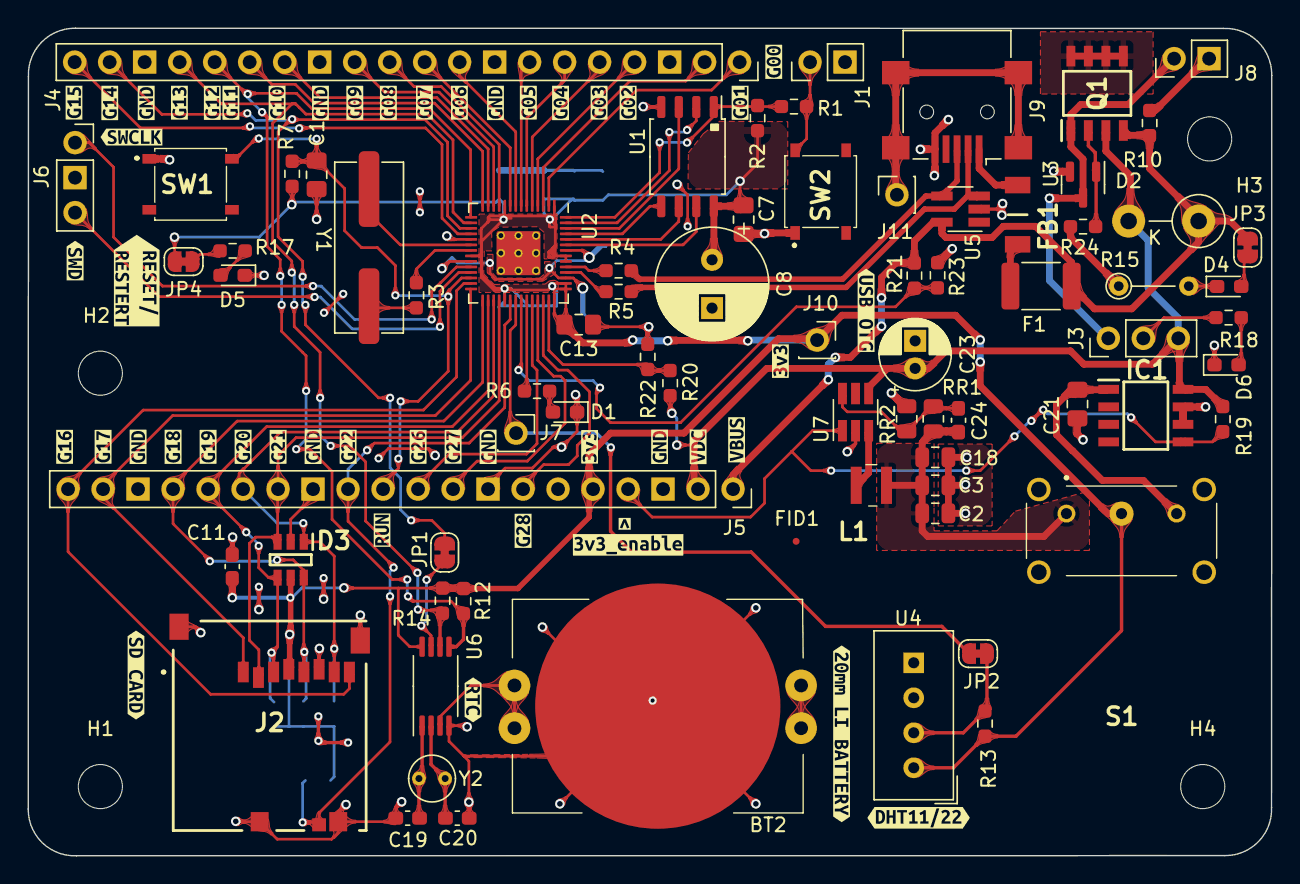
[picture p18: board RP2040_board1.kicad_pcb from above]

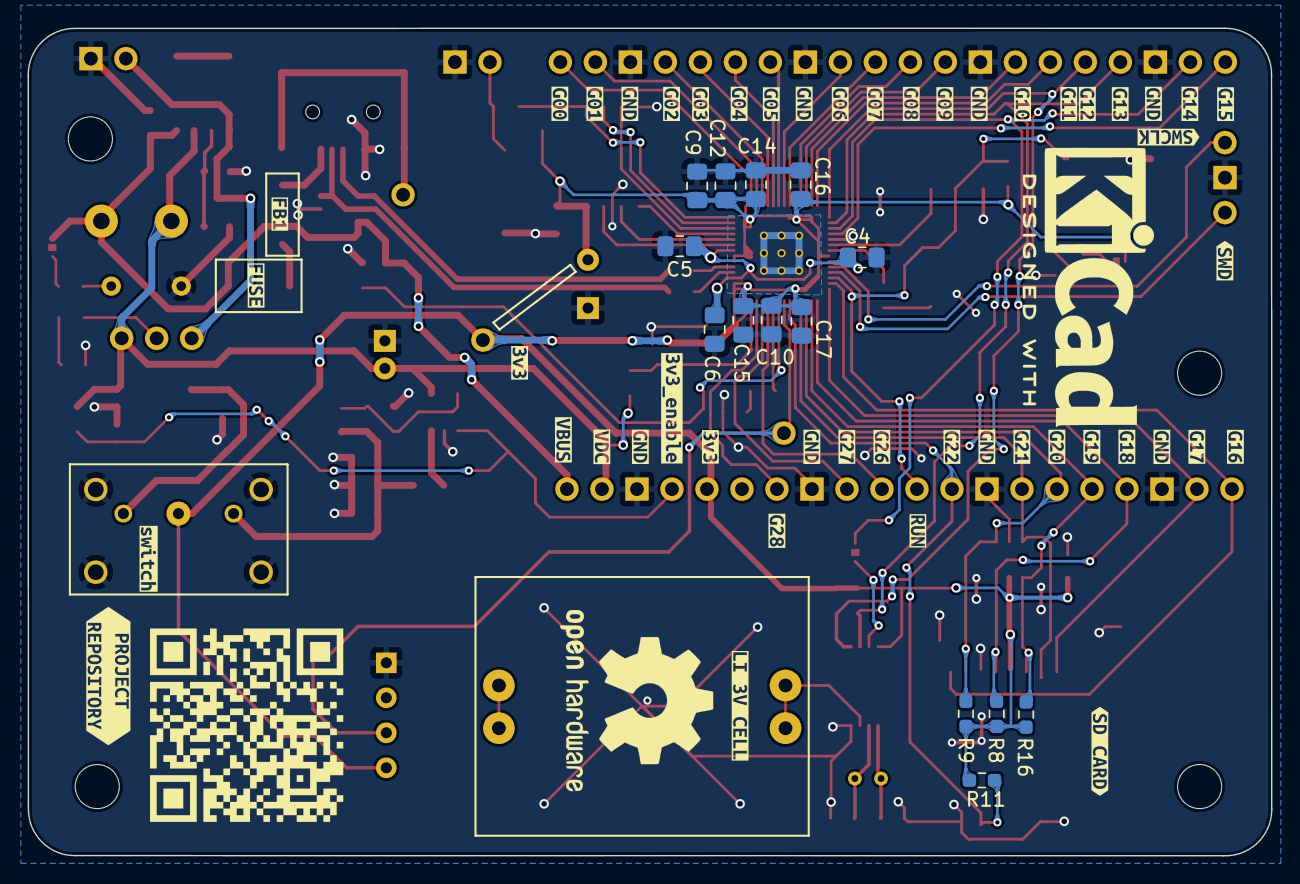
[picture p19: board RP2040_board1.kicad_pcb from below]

Board: 2 copper layers, 90.2 x 60.1 mm, 192 parts (65 on the bottom side), 75 nets.

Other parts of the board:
 : LOGO
kibuzzard-626E75F6, kibuzzard-626E75F6#2: G***; kibuzzard-626E75F6
kibuzzard-626E76A5, kibuzzard-626E76A5#2: G***; kibuzzard-626E76A5
kibuzzard-626E76AE, kibuzzard-626E76AE#2: G***; kibuzzard-626E76AE
kibuzzard-626E76B5, kibuzzard-626E76B5#2: G***; kibuzzard-626E76B5
kibuzzard-626E76C0, kibuzzard-626E76C0#2: G***; kibuzzard-626E76C0
kibuzzard-626E76C6, kibuzzard-626E76C6#2: G***; kibuzzard-626E76C6
kibuzzard-626E76CD, kibuzzard-626E76CD#2: G***; kibuzzard-626E76CD
kibuzzard-626E76D2, kibuzzard-626E76D2#2: G***; kibuzzard-626E76D2
kibuzzard-626E76E0, kibuzzard-626E76E0#2: G***; kibuzzard-626E76E0
kibuzzard-626E76E7, kibuzzard-626E76E7#2: G***; kibuzzard-626E76E7
kibuzzard-626E94A4: G***; kibuzzard-626E94A4
kibuzzard-626E96A8, kibuzzard-626E96A8#2: G***; kibuzzard-626E96A8
kibuzzard-626E96B6, kibuzzard-626E96B6#2, kibuzzard-626E96B6#3, kibuzzard-626E96B6#4: G***; kibuzzard-626E96B6
kibuzzard-626E96C2, kibuzzard-626E96C2#2: G***; kibuzzard-626E96C2
kibuzzard-626E96E0: G***; kibuzzard-626E96E0
kibuzzard-626E96EE, kibuzzard-626E96EE#2: G***; kibuzzard-626E96EE
kibuzzard-626E96FC, kibuzzard-626E96FC#2: G***; kibuzzard-626E96FC
kibuzzard-626E98D2, kibuzzard-626E98D2#2: G***; kibuzzard-626E98D2
kibuzzard-626E760F, kibuzzard-626E760F#2: G***; kibuzzard-626E760F
kibuzzard-626E761A, kibuzzard-626E761A#2: G***; kibuzzard-626E761A
kibuzzard-626E769F, kibuzzard-626E769F#2: G***; kibuzzard-626E769F
kibuzzard-626E937A: G***; kibuzzard-626E937A
kibuzzard-626E946D: G***; kibuzzard-626E946D
kibuzzard-626E948F: G***; kibuzzard-626E948F
kibuzzard-626E966C, kibuzzard-626E966C#2: G***; kibuzzard-626E966C
kibuzzard-626E968A, kibuzzard-626E968A#2: G***; kibuzzard-626E968A
kibuzzard-626E969D, kibuzzard-626E969D#2: G***; kibuzzard-626E969D
kibuzzard-626E977A, kibuzzard-626E977A#2: G***; kibuzzard-626E977A
kibuzzard-626E7343, kibuzzard-626E7343#2: G***; kibuzzard-626E7343
kibuzzard-626E7607, kibuzzard-626E7607#2, kibuzzard-626E7607#3, kibuzzard-626E7607#4, kibuzzard-626E7607#5, kibuzzard-626E7607#6, kibuzzard-626E7607#7, kibuzzard-626E7607#8, kibuzzard-626E7607#9, kibuzzard-626E7607#10, kibuzzard-626E7607#11, kibuzzard-626E7607#12, kibuzzard-626E7607#13, kibuzzard-626E7607#14, kibuzzard-626E7607#15: G***; kibuzzard-626E7607
kibuzzard-626E7622, kibuzzard-626E7622#2: G***; kibuzzard-626E7622
kibuzzard-626E7694, kibuzzard-626E7694#2: G***; kibuzzard-626E7694
kibuzzard-626E9458, kibuzzard-626E9458#2: G***; kibuzzard-626E9458
kibuzzard-626E9527, kibuzzard-626E9527#2: G***; kibuzzard-626E9527
kibuzzard-626E9537, kibuzzard-626E9537#2: G***; kibuzzard-626E9537
kibuzzard-626E9677, kibuzzard-626E9677#2: G***; kibuzzard-626E9677
kibuzzard-626E9683, kibuzzard-626E9683#2: G***; kibuzzard-626E9683
kibuzzard-626E9692, kibuzzard-626E9692#2: G***; kibuzzard-626E9692
kibuzzard-626ED31B, kibuzzard-626ED31B#2: G***; kibuzzard-626ED31B
kibuzzard-626ED41E: G***; kibuzzard-626ED41E
kibuzzard-626ED45F: G***; kibuzzard-626ED45F
kibuzzard-626ED354, kibuzzard-626ED354#2: G***; kibuzzard-626ED354
kibuzzard-626ED435: G***; kibuzzard-626ED435
kibuzzard-626ED447: G***; kibuzzard-626ED447
kibuzzard-627E9976: G***; kibuzzard-627E9976
kibuzzard-6275430A: G***; kibuzzard-6275430A

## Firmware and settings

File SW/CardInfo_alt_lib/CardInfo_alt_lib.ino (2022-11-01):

/****************************************************************************************************************************
  CardInfo.ino

  For all RP2040 boads using Arduimo-mbed or arduino-pico core

  RP2040_SD is a library enable the usage of SD on RP2040-based boards

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
  Based on and modified from  Arduino SdFat Library (https://github.com/arduino/Arduino)

  (C) Copyright 2009 by William Greiman
  (C) Copyright 2010 SparkFun Electronics
  (C) Copyright 2021 by Khoi Hoang

  Built by Khoi Hoang https://github.com/khoih-prog/RP2040_SD
  Licensed under GPL-3.0 license
 *****************************************************************************************************************************/
/*
  SD card connection

  This example shows how to read and write data to and from an SD card file
  The circuit:
   SD card attached to SPI bus as follows:
   // Arduino-pico core
   ** MISO - pin 16
   ** MOSI - pin 19
   ** CS   - pin 17
   ** SCK  - pin 18

   // Arduino-mbed core
   ** MISO - pin 4
   ** MOSI - pin 3
   ** CS   - pin 5
   ** SCK  - pin 2
*/



/*
#define PIN_SPI_SC 21
#define PIN_SPI_MISO 20
#define PIN_SPI_MOSI 19
#define PIN_SPI_SCK 18
*/



#if !defined(ARDUINO_ARCH_RP2040)
#error For RP2040 only
#endif

#if defined(ARDUINO_ARCH_MBED)

#define PIN_SD_MOSI       PIN_SPI_MOSI
#define PIN_SD_MISO       PIN_SPI_MISO
#define PIN_SD_SCK        PIN_SPI_SCK
#define PIN_SD_SS         PIN_SPI_SS

#else

#define PIN_SD_MOSI       PIN_SPI0_MOSI
#define PIN_SD_MISO       PIN_SPI0_MISO
#define PIN_SD_SCK        PIN_SPI0_SCK
#define PIN_SD_SS         PIN_SPI0_SS

#endif

#define PIN_SPI_SS 5
#define PIN_SPI_MISO 4
#define PIN_SPI_MOSI 3
#define PIN_SPI_SCK 2

#define PIN_SD_MOSI       3
#define PIN_SD_MISO       4
#define PIN_SD_SCK        2
#define PIN_SD_SS         5


#define _RP2040_SD_LOGLEVEL_       0

#include <SPI.h>
#include <RP2040_SD.h>

// set up variables using the SD utility library functions:
Sd2Card card;
SdVolume volume;
File root;

const int chipSelect = PIN_SD_SS;

void printDirectory(File dir, int numTabs)
{
  while (true)
  {
    File entry =  dir.openNextFile();

    if (! entry)
    {
      // no more files
      break;
    }

    for (uint8_t i = 0; i < numTabs; i++)
    {
      Serial.print('\t');
    }

    Serial.print(entry.name());

    if (entry.isDirectory())
    {
      Serial.println("/");
      printDirectory(entry, numTabs + 1);
    }
    else
    {
      // files have sizes, directories do not
      Serial.print("\t\t");
      Serial.println(entry.size(), DEC);
    }

    entry.close();
  }
}

void setup()
{
  // Open serial communications and wait for port to open:
  Serial.begin(115200);
  while (!Serial);

  delay(1000);

#if defined(ARDUINO_ARCH_MBED)
  Serial.print("Starting SD Card CardInfo on MBED ");
#else
  Serial.print("Starting SD Card CardInfo on ");  
  Serial.print("test does it even upload well?");
#endif

  Serial.println(BOARD_NAME);
  Serial.println(RP2040_SD_VERSION);

  Serial.print("Initializing SD card with SS = ");  Serial.println(PIN_SD_SS);
  Serial.print("SCK = ");   Serial.println(PIN_SD_SCK);
  Serial.print("MOSI = ");  Serial.println(PIN_SD_MOSI);
  Serial.print("MISO = ");  Serial.println(PIN_SD_MISO);

  // we'll use the initialization code from the utility libraries
  // since we're just testing if the card is working!
  if (!card.init(SPI_HALF_SPEED, chipSelect))
  {
    Serial.println("initialization failed. Things to check:");
    Serial.println("* is a card inserted?");
    Serial.println("* is your wiring correct?");
    Serial.println("* did you change the chipSelect pin to match your shield or module?");
    while (1);
  }
  else
  {
    Serial.println("Wiring is correct and a card is present.");
  }

  // print the type of card
  Serial.println();
  Serial.print("Card type:         ");

  switch (card.type())
  {
  case SD_CARD_TYPE_SD1:
    Serial.println("SD1");
    break;
  case SD_CARD_TYPE_SD2:
    Serial.println("SD2");
    break;
  case SD_CARD_TYPE_SDHC:
    Serial.println("SDHC");
    break;
  default:
    Serial.println("Unknown");
  }

  // Now we will try to open the 'volume'/'partition' - it should be FAT16 or FAT32
  if (!volume.init(card))
  {
    Serial.println("Could not find FAT16/FAT32 partition.\nMake sure you've formatted the card");
    while (1);
  }

  Serial.print("Clusters:          ");
  Serial.println(volume.clusterCount());
  Serial.print("Blocks x Cluster:  ");
  Serial.println(volume.blocksPerCluster());

  Serial.print("Total Blocks:      ");
  Serial.println(volume.blocksPerCluster() * volume.clusterCount());
  Serial.println();

  // print the type and size of the first FAT-type volume
  uint32_t volumesize;
  Serial.print("Volume type is:    FAT");
  Serial.println(volume.fatType(), DEC);

  volumesize = volume.blocksPerCluster();    // clusters are collections of blocks
  volumesize *= volume.clusterCount();       // we'll have a lot of clusters
  volumesize /= 2;                           // SD card blocks are always 512 bytes (2 blocks are 1KB)
  Serial.print("Volume size (Kb):  ");
  Serial.println(volumesize);
  Serial.print("Volume size (Mb):  ");
  volumesize /= 1024;
  Serial.println(volumesize);
  Serial.print("Volume size (Gb):  ");
  Serial.println((float)volumesize / 1024.0);

  if (!SD.begin(PIN_SD_SS))
  {
    Serial.println("Initialization failed!");
    return;
  }

  Serial.println("Initialization done.");

  Serial.println("\nFiles found on the card (name, date and size in bytes): ");

  root = SD.open("/");

  printDirectory(root, 0);
}

void loop()
{
}

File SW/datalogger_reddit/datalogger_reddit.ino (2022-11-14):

/*
  SD card datalogger

  This example shows how to log data from three analog sensors
  to an SD card using the SD library.

  The circuit:
   analog sensors on analog ins 0, 1, and 2
   SD card attached to SPI bus as follows (Raspberry Pi Pico):
   ** MISO - pin 0
   ** MOSI - pin 3
   ** CS   - pin 1
   ** SCK  - pin 2

  created  24 Nov 2010
  modified 9 Apr 2012
  by Tom Igoe

  This example code is in the public domain.

*/

#include <SPI.h>
#include <SD.h>

const int chipSelect = 5;

void setup() {
    SPI.setTX(3);
  SPI.setRX(4);
  SPI.setSCK(2);
  SPI.setCS(5);
  // Open serial communications and wait for port to open:
  Serial.begin(115200);

  Serial.print("Initializing SD card...");

  // see if the card is present and can be initialized:
  if (!SD.begin(chipSelect)) {
    Serial.println("Card failed, or not present");
    // don't do anything more:
    return;
  }
  Serial.println("card initialized.");
}

void loop() {
  // make a string for assembling the data to log:
  String dataString = "";

  // read three sensors and append to the string:
  for (int analogPin = 0; analogPin < 3; analogPin++) {
    int sensor = analogRead(analogPin);
    dataString += String(sensor);
    if (analogPin < 2) {
      dataString += ",";
    }
  }

  // open the file. note that only one file can be open at a time,
  // so you have to close this one before opening another.
  File dataFile = SD.open("datalog.txt", FILE_WRITE);

  // if the file is available, write to it:
  if (dataFile) {
    dataFile.println(dataString);
    dataFile.close();
    // print to the serial port too:
    Serial.println(dataString);
  }
  // if the file isn't open, pop up an error:
  else {
    Serial.println("error opening datalog.txt test upload here");
  }
}

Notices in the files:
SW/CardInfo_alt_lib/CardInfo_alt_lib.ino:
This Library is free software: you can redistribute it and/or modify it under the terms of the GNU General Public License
